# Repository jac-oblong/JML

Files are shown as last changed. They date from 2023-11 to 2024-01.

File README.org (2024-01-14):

* JML
Line of computers built mostly from scrap.

#+CAPTION: JML Logo
#+ATTR_HTML: :width 600px :style margin-left: auto; margin-right: auto;
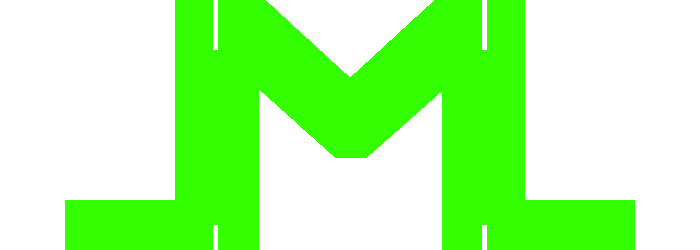
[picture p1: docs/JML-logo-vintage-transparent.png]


* Table of Contents :toc:
- [[#jml][JML]]
- [[#design][Design]]
- [[#parts][Parts]]
- [[#folder-organization][Folder Organization]]
- [[#families][Families]]
  - [[#jml-8][JML-8]]

* Design
The line of *JML* computers is broken into "families". Each family is
designated by a number, for example the *JML-8* family of computer. Each model
in that family is further distinguished by a name, for example the
*JML-8-Mini*.

* Parts
Almost all parts have been scrapped from other computers/electronics. Many of
these parts are from very old computers and are no longer on the market.

Modern day equivalents do exist, but it is necessary to be cautious about
differing pin-outs. It may be necessary to design a new PCB for a modern
chip, or at least a way to change pin-out.

* Folder Organization
Information about the different model computers can be found in any
directory titled *JML-{family}-{model}*.

* Families
Below is a list of all families with a brief description of each family.

- [[#jml-8][JML-8]]

** JML-8
This is a family of 8-bit microcomputers designed around the Z80
microprocessor.

- [[#jml-8-mini][JML-8-Mini]]

*** JML-8-Mini
[[file:jml-8-mini][This model]] uses a UART serial port to communicate with a terminal.
An FTDI chip can be used to send data from a computer to the
Z80.

The "operating system" this model runs only allows for very simple
commands. These commands allow the user to read the values at
memory locations, write values to memory locations and transfer
program control to a specific memory location. Additionally, there is a built
in BASIC interpreter.

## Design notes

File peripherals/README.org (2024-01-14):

* Peripherals
This directory contains information regarding custom peripherals.
Some of the peripherals are designed as add-ons/expansions to other
models, and others are designed as entirely distinct boards that are
in some way related to the *JML* project.

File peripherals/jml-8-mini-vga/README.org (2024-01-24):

* JML-8-Mini VGA

#+ATTR_HTML: :width 600px
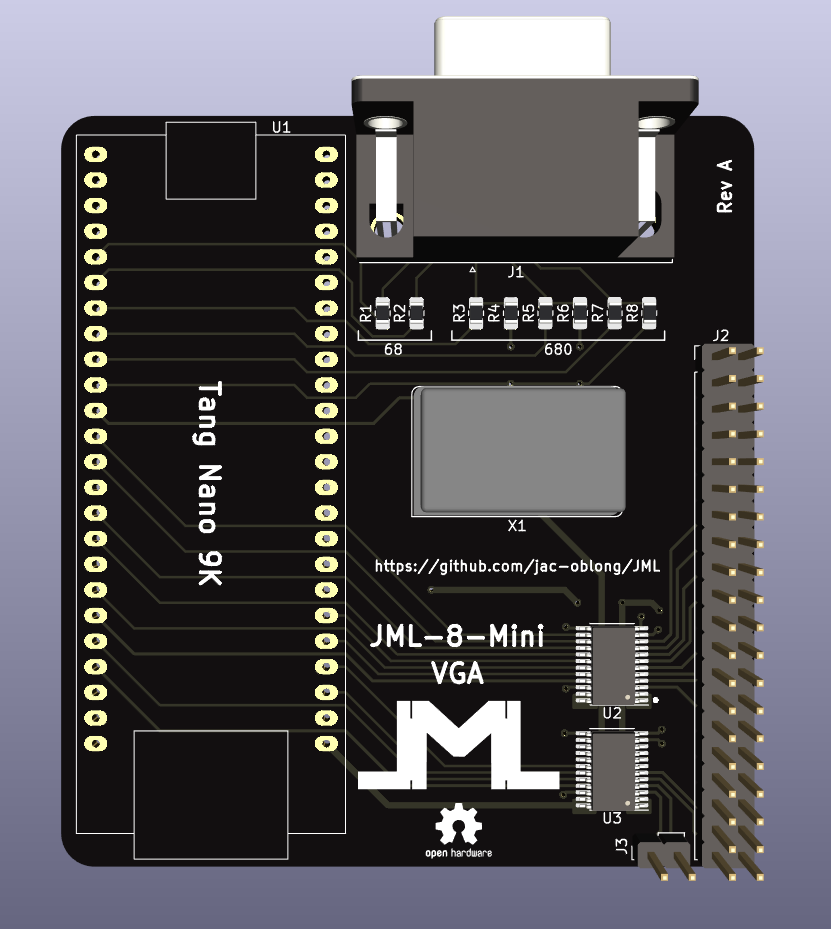
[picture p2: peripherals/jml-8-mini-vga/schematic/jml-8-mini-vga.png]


This provides a VGA interface to the JML-8-Mini via a Tang Nano 9k FPGA.
The daughterboard plugs into the the Z80 header pins on the JML-8-Mini.

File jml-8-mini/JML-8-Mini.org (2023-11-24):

#+title: JML-8-Mini

#+CAPTION: JML-8-Mini PCB
#+ATTR_HTML: :width 600px
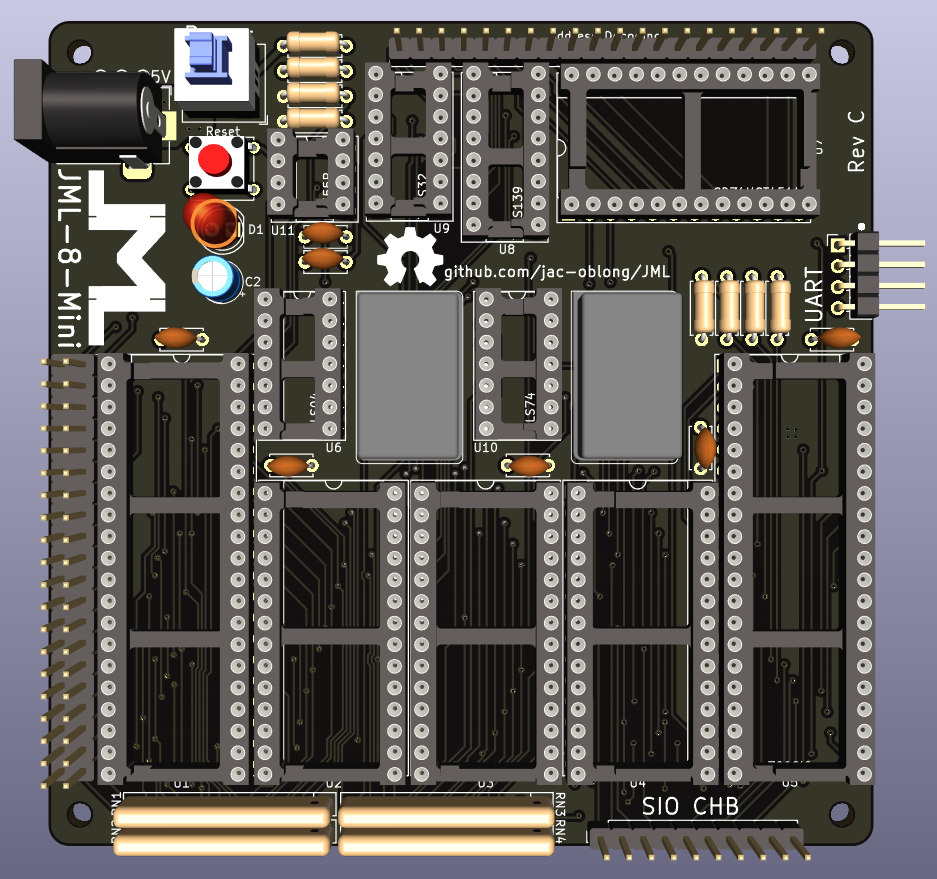
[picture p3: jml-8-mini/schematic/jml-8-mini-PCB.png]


* Table of Contents :toc:
- [[#description--features][Description & Features]]
- [[#usage][Usage]]
  - [[#creating-your-own][Creating Your Own]]
- [[#design-overview][Design Overview]]

* Description & Features
The *JML-8-Mini* is an 8-bit computer using the Z80 microprocessor. The computer
has a built-in BASIC interpreter as well as a simple memory monitor.

*Features:*
 - 8k of ROM (BASIC and Memory Monitor)
 - 32k of RAM
 - BASIC Interpreter (Based on Grant Searle's Version of NASCOM BASIC)
 - UART Interface (Z80 SIO & Z80 CTC)
 - Extra Serial I/0 Port (Z80 SIO CHB)
 - 3 Extra Counter/Timer Circuits (Z80 CTC CH1-3)

* Usage
The barrel jack can be used to power the board. It requires 5V DC
center-positive.

Since the computer communicates over UART, a device that accepts serial
communication is needed. If using a computer, an FTDI device or even a
micro-controller can be used to convert from UART to USB. Any terminal
application should work for communication. The UART protocol used is 8-N-1
at 9600 baud. The order of the UART connection (starting on the end of the
connector with the black dot) is GND-TX-RX-CTS, NOTE: those labels are from
the viewpoint of an external device, not the JML-8-Mini.

On boot-up, the computer will be placed in the memory monitor program. BASIC
can be entered by pressing 'B' (case does not matter). However, there are
four other commands:
 - *W*: Write data into memory. After pressing 'W', enter the location in
   memory to write to in hex (4 digits required). Then, write the data to be
   written starting at that location. All data must be formatted in hex (2
   digits) and separated by another character (the character does not matter).
   A newline (carriage return)(0x0D) will signify that the write has ended.
 - *R*: Read data from memory. After pressing 'R', enter the location in
   memory to read from in hex (4 digits required). Then enter a dummy
   character, followed by the location in memory to stop reading from in hex.
   A newline will begin printing the data (in hex).
 - *J*: Jump to a location in memory. After pressing 'J', enter the location
   in memory to jump to in hex (4 digits required). The computer will execute
   an unconditional jump to that location.
 - *C*: Clear the screen.

** Creating Your Own
The [[file:./schematic/jml-8-mini-schematic.pdf][schematic]], [[file:./schematic/gerber][gerbers]] and [[file:./case/][case]] are all available in this repository. Be
careful when sourcing components; the CD74HCT4514E is a 4-16 line decoder,
but does not have the same footprint as other 4-16 decoders. A way to change
pin-outs may be necessary.

The BASIC code can be obtained from [[http://searle.wales][Grant Searle's Website]]. There are only
two changes that need to be made:
  1) Around line 130, there is a line with ~.org 04000H~, this needs to be
     changed to ~.org 00380H~
  2) At the very end of the file, the ~.end~ should be removed
Everything else can stay the same. The file should be named "basic.s" and
placed in the [[file:./src/][src]] directory.

There is [[file:../related-projects/][Arduino-based EEPROM programmer]] that may be helpful.

* Design Overview
The *JML-8-Mini*'s memory map can be seen below.

#+CAPTION: JML-8-Mini Memory Map
#+ATTR_HTML: :width 400px
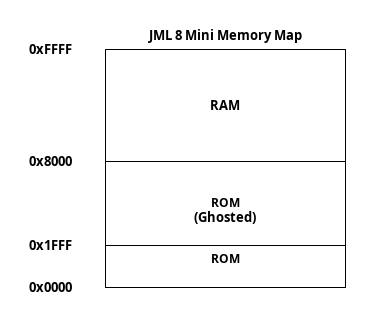
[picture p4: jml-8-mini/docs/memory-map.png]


The section of memory between ~0x1FFF~ and ~0x8000~ is a repetition of the ROM
because the ROM will still be enabled.

The I/O memory map is shown below.

#+CAPTION: JML-8-Mini Memory Map
#+ATTR_HTML: :width 300px
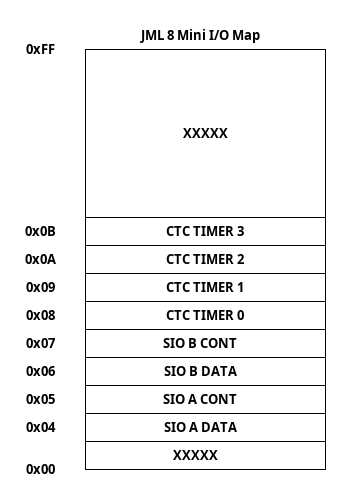
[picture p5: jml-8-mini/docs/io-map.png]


The extra headers on the board (address decoding, Z80 lines, SIO-CHB) allow
for more features to be added as I/O.

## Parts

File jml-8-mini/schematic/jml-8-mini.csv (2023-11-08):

# | Reference | Qty | Value | Footprint | DNP
1 | C1 | 1 | 0.001uF | Capacitor_THT:C_Disc_D5.0mm_W2.5mm_P5.00mm
2 | C2 | 1 | 1uF | Capacitor_THT:CP_Radial_D5.0mm_P2.50mm
3 | C3 | 1 | 0.1uF | Capacitor_THT:C_Disc_D5.0mm_W2.5mm_P5.00mm
4 | C4, C5, C6, C7, C8 | 5 | 2.2uF | Capacitor_THT:C_Disc_D5.0mm_W2.5mm_P5.00mm
5 | D1 | 1 | RED | LED_THT:LED_D5.0mm
6 | H1, H2, H3, H4 | 4 | MountingHole | MountingHole:MountingHole_2.7mm_M2.5
7 | J1 | 1 | BarrelJack | Connector_BarrelJack:BarrelJack_Horizontal
8 | J2 | 1 | SIO CHB | Connector_PinHeader_2.54mm:PinHeader_1x10_P2.54mm_Vertical
9 | J3 | 1 | UART | Connector_PinHeader_2.54mm:PinHeader_1x04_P2.54mm_Horizontal
10 | J5 | 1 | Address Decoding | Connector_PinHeader_2.54mm:PinHeader_1x20_P2.54mm_Vertical
11 | J6 | 1 | Z80 Lines | Connector_PinHeader_2.54mm:PinHeader_2x20_P2.54mm_Vertical
12 | R1, R2, R3, R8 | 4 | 4K7 | Resistor_THT:R_Axial_DIN0207_L6.3mm_D2.5mm_P7.62mm_Horizontal
13 | R4 | 1 | 100K | Resistor_THT:R_Axial_DIN0207_L6.3mm_D2.5mm_P7.62mm_Horizontal
14 | R5 | 1 | 47K | Resistor_THT:R_Axial_DIN0207_L6.3mm_D2.5mm_P7.62mm_Horizontal
15 | R6 | 1 | 10K | Resistor_THT:R_Axial_DIN0207_L6.3mm_D2.5mm_P7.62mm_Horizontal
16 | R7 | 1 | 2K2 | Resistor_THT:R_Axial_DIN0207_L6.3mm_D2.5mm_P7.62mm_Horizontal
17 | RN1, RN2, RN3, RN4 | 4 | 10K | Resistor_THT:R_Array_SIP10
18 | SW1 | 1 | Reset | Button_Switch_THT:SW_Tactile_Straight_KSA0Axx1LFTR
19 | SW2 | 1 | Power | Button_Switch_THT:SW_Push_2P2T_Toggle_CK_PVA2xxH1xxxxxxV2
20 | U1 | 1 | Z80CPU | Package_DIP:DIP-40_W15.24mm_Socket_LongPads
21 | U2 | 1 | 28HC64 | Package_DIP:DIP-28_W15.24mm_Socket_LongPads
22 | U3 | 1 | 60L256 | Package_DIP:DIP-28_W15.24mm_Socket_LongPads
23 | U4 | 1 | Z80CTC | Package_DIP:DIP-28_W15.24mm_Socket_LongPads
24 | U5 | 1 | Z80SIO | Package_DIP:DIP-40_W15.24mm_Socket_LongPads
25 | U6 | 1 | 74LS04 | Package_DIP:DIP-14_W7.62mm_Socket_LongPads
26 | U7 | 1 | CD74HCT4514E | Package_DIP:DIP-24_W15.24mm_Socket_LongPads
27 | U8 | 1 | 74LS139 | Package_DIP:DIP-16_W7.62mm_Socket_LongPads
28 | U9 | 1 | 74LS32 | Package_DIP:DIP-14_W7.62mm_Socket_LongPads
29 | U10 | 1 | 74LS74 | Package_DIP:DIP-14_W7.62mm_Socket_LongPads
30 | U11 | 1 | NE555P | Package_DIP:DIP-8_W7.62mm_Socket_LongPads
31 | X1 | 1 | 8MHz | Oscillator:Oscillator_DIP-14
32 | X2 | 1 | 2.4576MHz | Oscillator:Oscillator_DIP-14

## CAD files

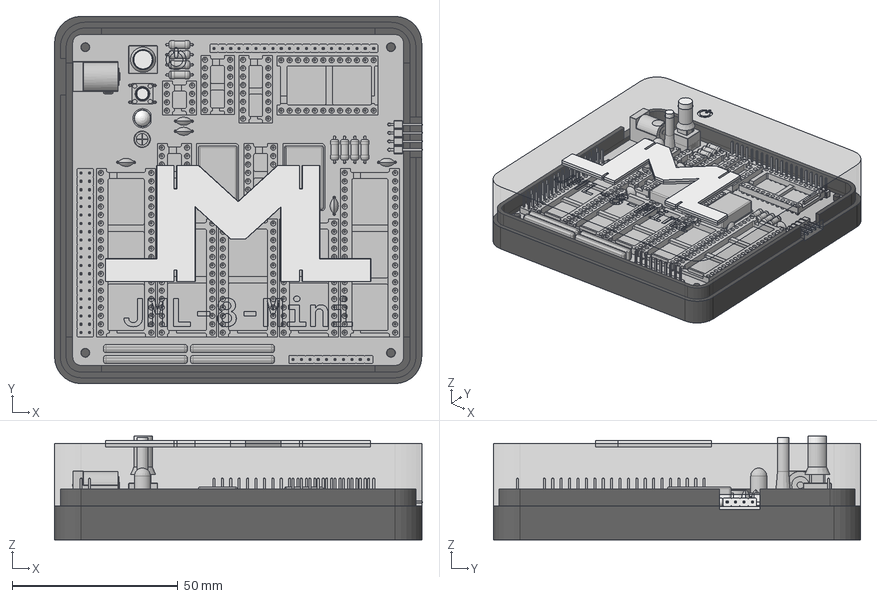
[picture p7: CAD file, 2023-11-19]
jml-8-mini/case/jml-8-mini-case-assembly.FCStd
111.2 x 110.9 x 31.3 mm
jml-8-mini-case-bottom_bottom_001
jml-8-mini1_001
jml-8-mini-case-top_reset-peg_001
jml-8-mini-case-top_power-peg_001
jml-8-mini-case-top_logo-fill_001
jml-8-mini-case-top_top-cut_001

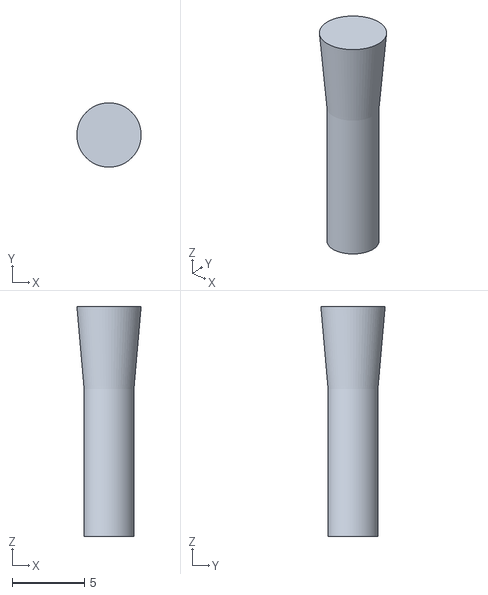
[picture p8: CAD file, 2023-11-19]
jml-8-mini/case/jml-8-mini-case-reset-peg.stl
4.45 x 4.45 x 15.9

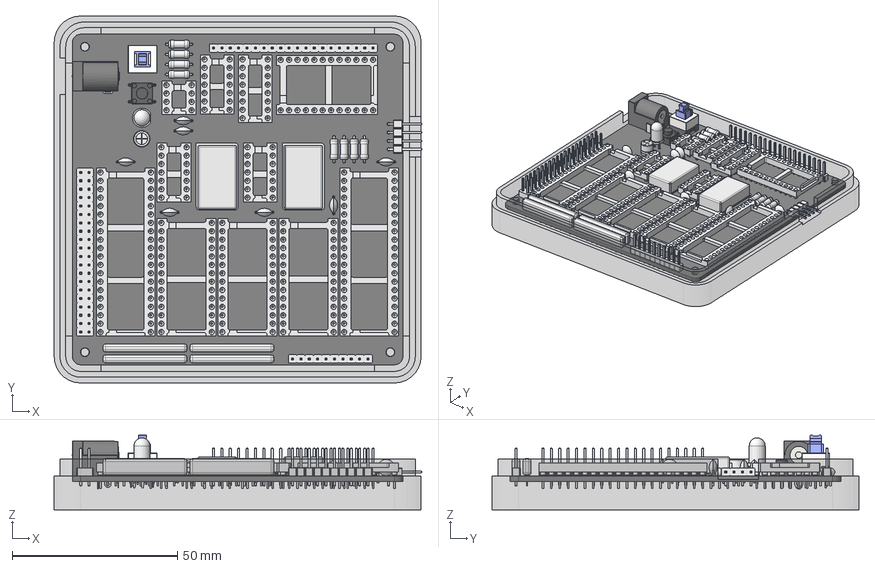
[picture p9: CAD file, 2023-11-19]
jml-8-mini/case/jml-8-mini-case-bottom.FCStd
111.2 x 110.9 x 22.6 mm
Pcb_da37
R1_R_Axial_DIN0207_L63mm_D25mm_P762mm_Horizontal_fb2dbf7774b0
U1_DIP_40_W1524mm_Socket_2b005913294a
X2_Oscillator_DIP-14_1cb9fdc6376d
U8_DIP_16_W762mm_Socket_50c2e2878be6
D1_LED_D5.0mm_c46ec44da1f9
U11_DIP_8_W762mm_Socket_8dfed9607c42
U3_DIP_28_W1524mm_Socket_90a58a7486b6
RN3_R_Array_SIP10_876d0d87e7f4
C5_C_Disc_D50mm_W25mm_P500mm_e6d4c14bf3d8
R1_R_Axial_DIN0207_L63mm_D25mm_P762mm_Horizontal_fb2dbf7774b001
C2_CP_Radial_D50mm_P250mm_b76e36c16755
RN3_R_Array_SIP10_876d0d87e7f005
U7_DIP_24_W1524mm_Socket_14ec14ce778c
U1_DIP_40_W1524mm_Socket_2b005913294a001
RN3_R_Array_SIP10_876d0d87e7f006
C5_C_Disc_D50mm_W25mm_P500mm_e6d4c14bf3d009
U9_DIP_14_W762mm_Socket_89bedef5e4b6
J2_PinHeader_1x10_P254mm_Vertical_b87f2ee21f90
SW1_buttonRot_e16b7170c22b
R1_R_Axial_DIN0207_L63mm_D25mm_P762mm_Horizontal_fb2dbf7774b002
U3_DIP_28_W1524mm_Socket_90a58a7486b007
J6_PinHeader_2x20_P254mm_Vertical_cfeccff21bfa
BarrelJack_Horizontal
BarrelJack_Horizontal001
BarrelJack_Horizontal002
BarrelJack_Horizontal003
BarrelJack_Horizontal004
ON_ON_7x7mm_6pin v014
ON_ON_7x7mm_6pin v015
ON_ON_7x7mm_6pin v016
ON_ON_7x7mm_6pin v017
ON_ON_7x7mm_6pin v018
ON_ON_7x7mm_6pin v019
ON_ON_7x7mm_6pin v020
ON_ON_7x7mm_6pin v021
ON_ON_7x7mm_6pin v022
R1_R_Axial_DIN0207_L63mm_D25mm_P762mm_Horizontal_fb2dbf7774b003
C5_C_Disc_D50mm_W25mm_P500mm_e6d4c14bf3d010
R1_R_Axial_DIN0207_L63mm_D25mm_P762mm_Horizontal_fb2dbf7774b004
J5_PinHeader_1x20_P254mm_Vertical_dfc64bbc94d7
R1_R_Axial_DIN0207_L63mm_D25mm_P762mm_Horizontal_fb2dbf7774b005
R1_R_Axial_DIN0207_L63mm_D25mm_P762mm_Horizontal_fb2dbf7774b006
C5_C_Disc_D50mm_W25mm_P500mm_e6d4c14bf3d011
RN3_R_Array_SIP10_876d0d87e7f007
C5_C_Disc_D50mm_W25mm_P500mm_e6d4c14bf3d012
C5_C_Disc_D50mm_W25mm_P500mm_e6d4c14bf3d013
U3_DIP_28_W1524mm_Socket_90a58a7486b008
R1_R_Axial_DIN0207_L63mm_D25mm_P762mm_Horizontal_fb2dbf7774b007
J3_PinHeader_1x04_P254mm_Horizontal_bb1bdafc893f
C5_C_Disc_D50mm_W25mm_P500mm_e6d4c14bf3d014
U9_DIP_14_W762mm_Socket_89bedef5e4b007
X2_Oscillator_DIP-14_1cb9fdc6376d001
U9_DIP_14_W762mm_Socket_89bedef5e4b008
bottom

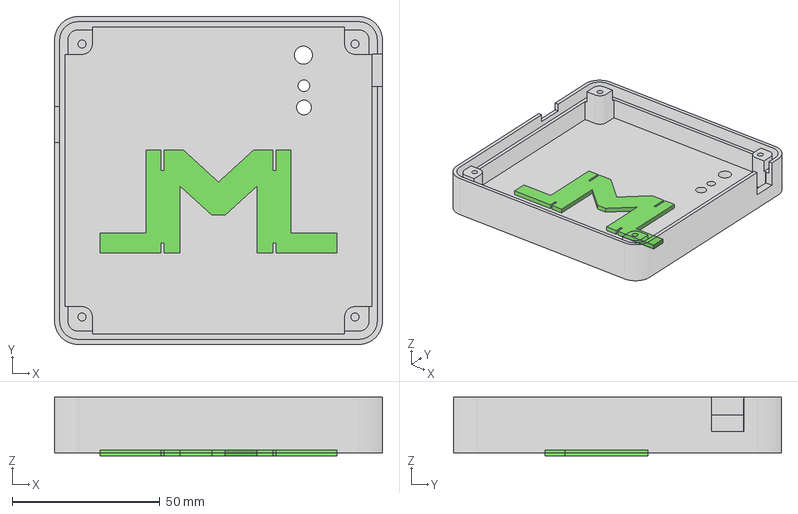
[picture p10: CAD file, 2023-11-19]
jml-8-mini/case/jml-8-mini-case-top.FCStd
110.9 x 110.9 x 19.9 mm
top-cut
logo-fill

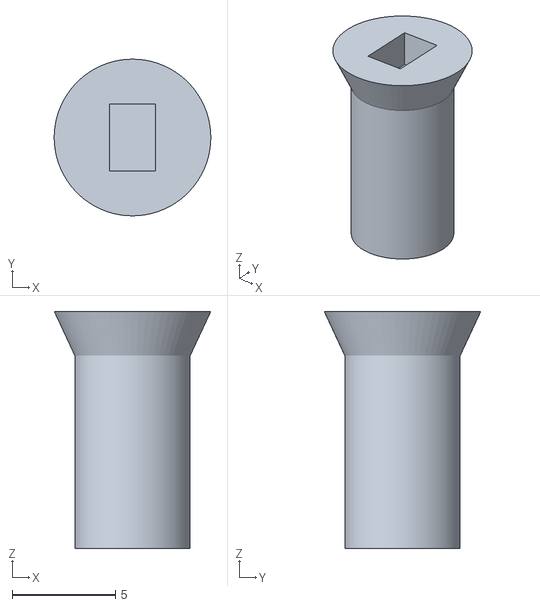
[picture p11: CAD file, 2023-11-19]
jml-8-mini/case/jml-8-mini-case-power-peg.stl
7.60 x 7.60 x 11.5

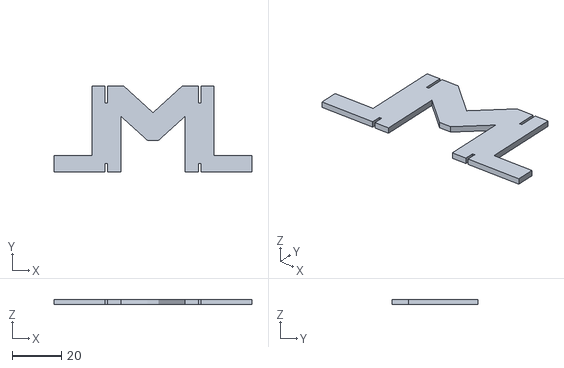
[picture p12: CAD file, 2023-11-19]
jml-8-mini/case/jml-8-mini-case-logo.stl
80.0 x 35.0 x 2.00

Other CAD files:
jml-8-mini/case/jml-8-mini-case-bottom.stl
jml-8-mini/case/jml-8-mini-case-top.stl

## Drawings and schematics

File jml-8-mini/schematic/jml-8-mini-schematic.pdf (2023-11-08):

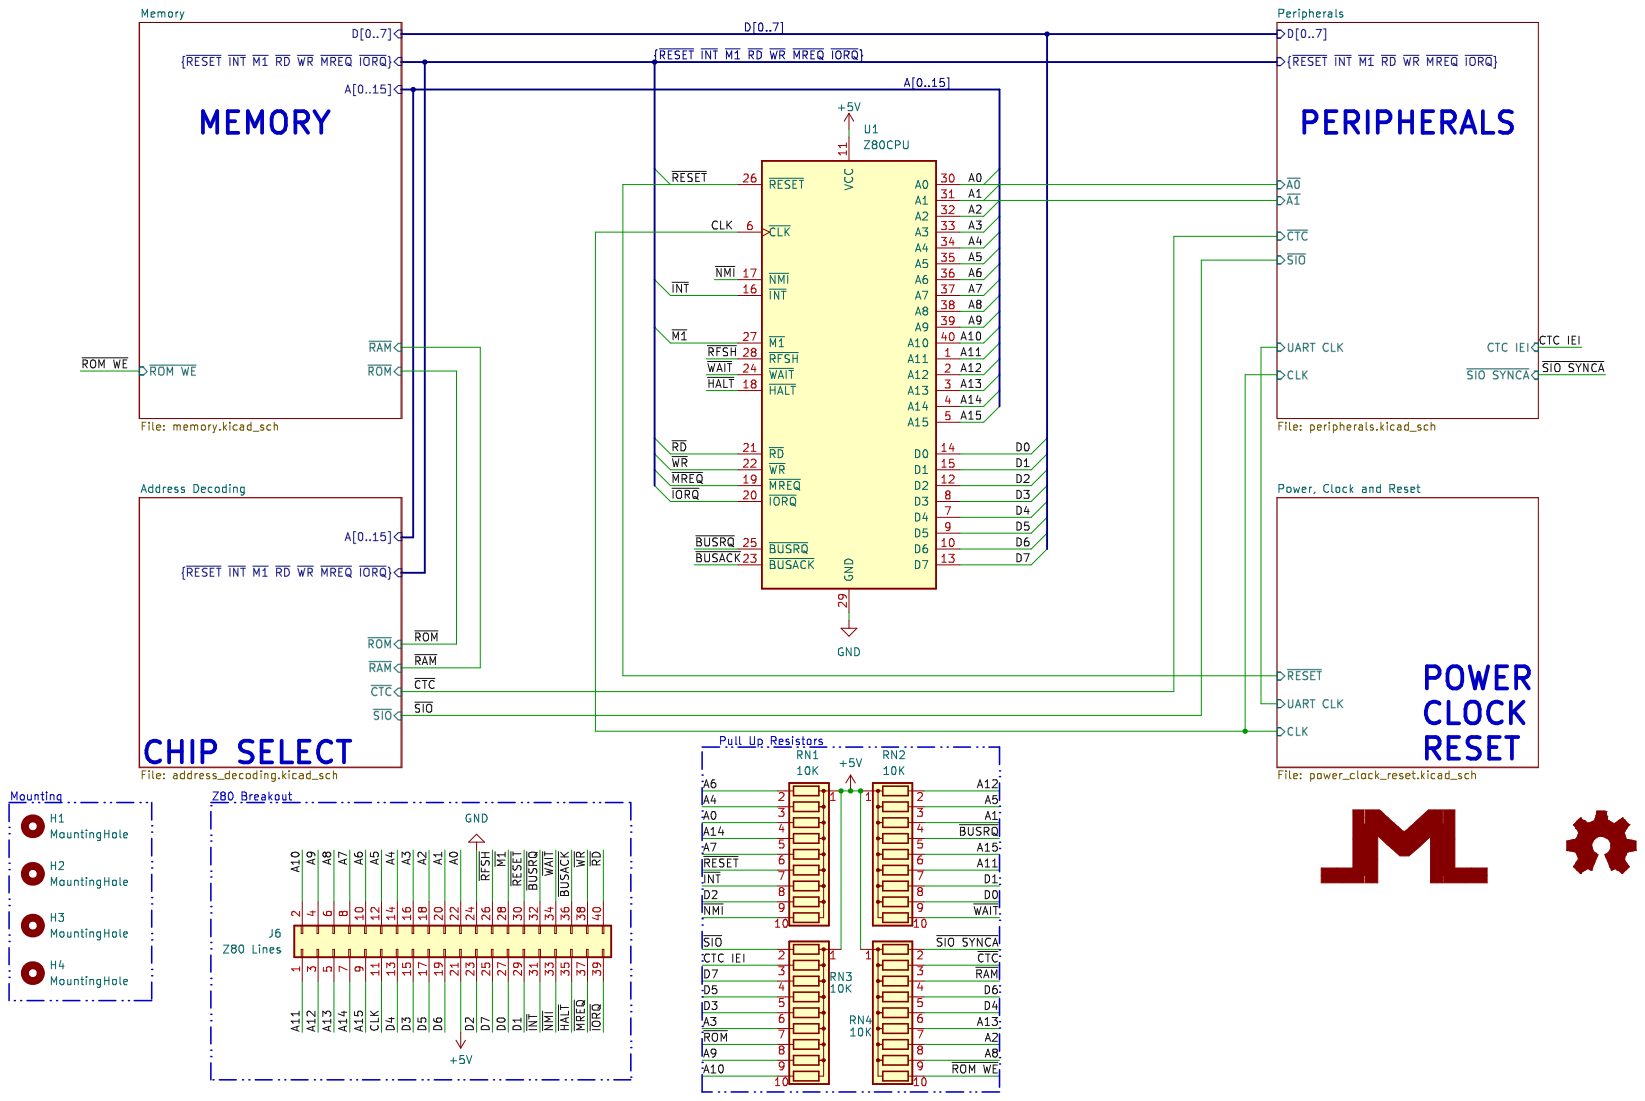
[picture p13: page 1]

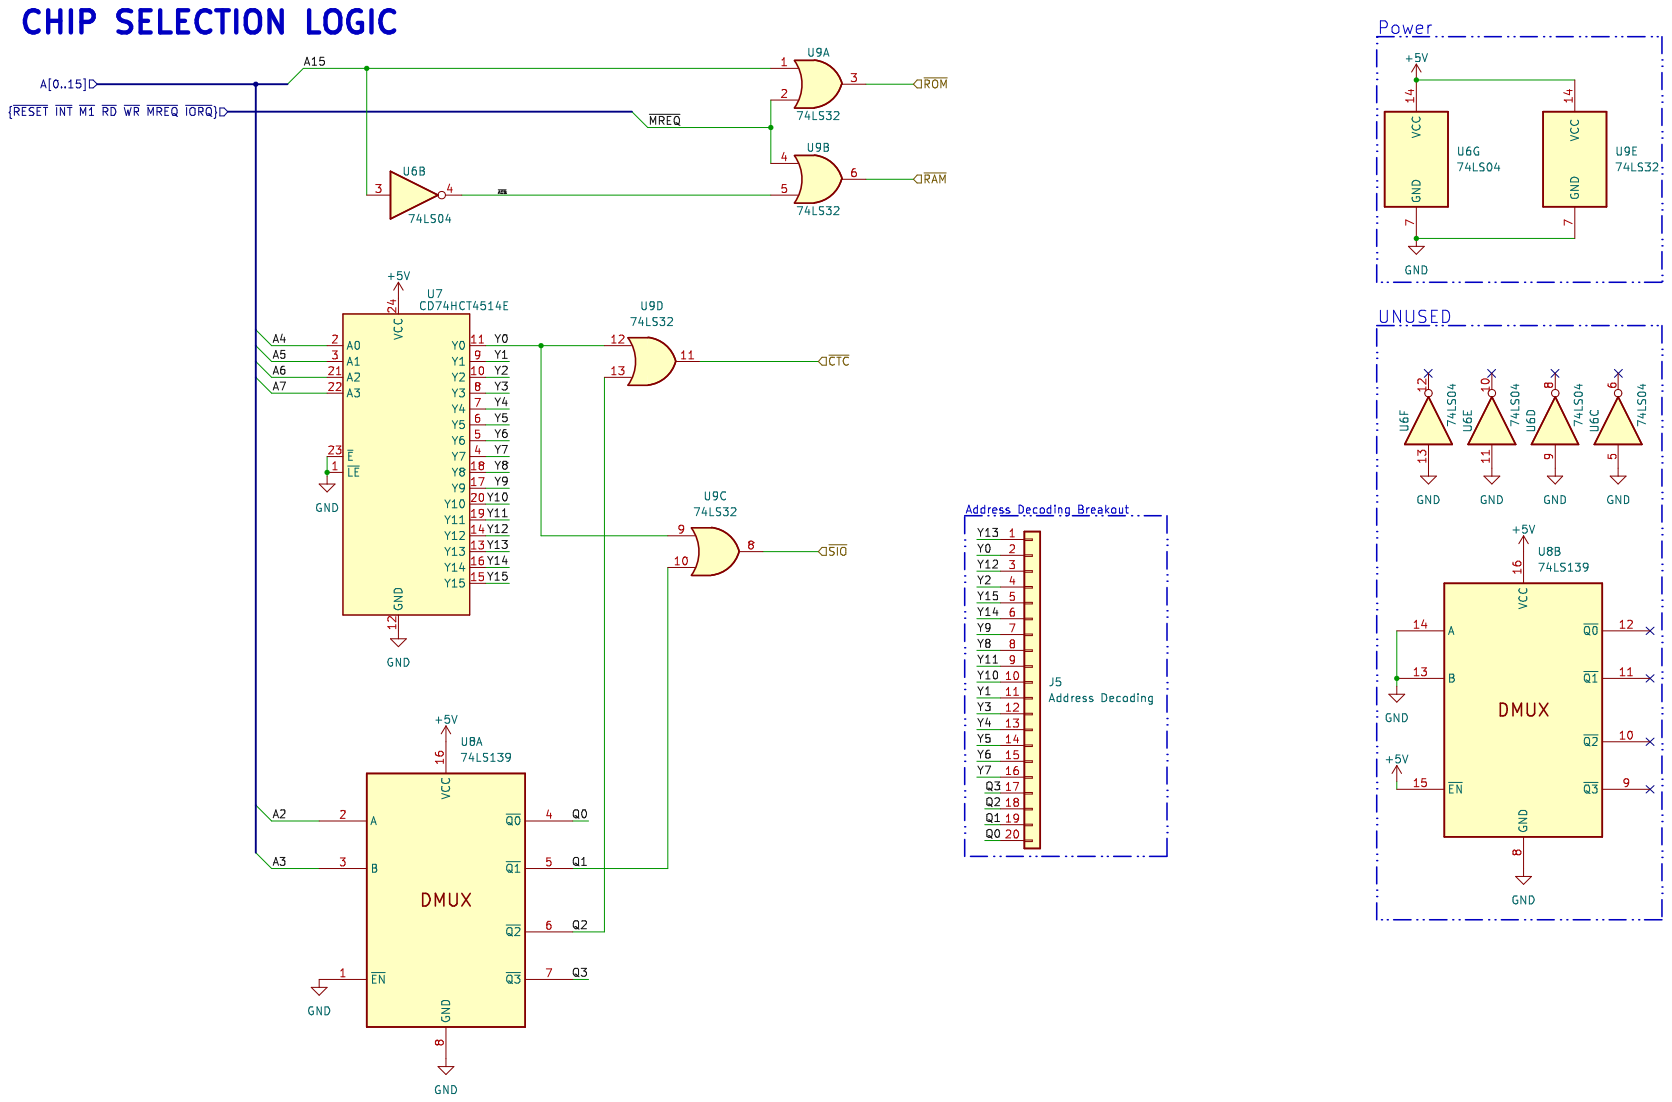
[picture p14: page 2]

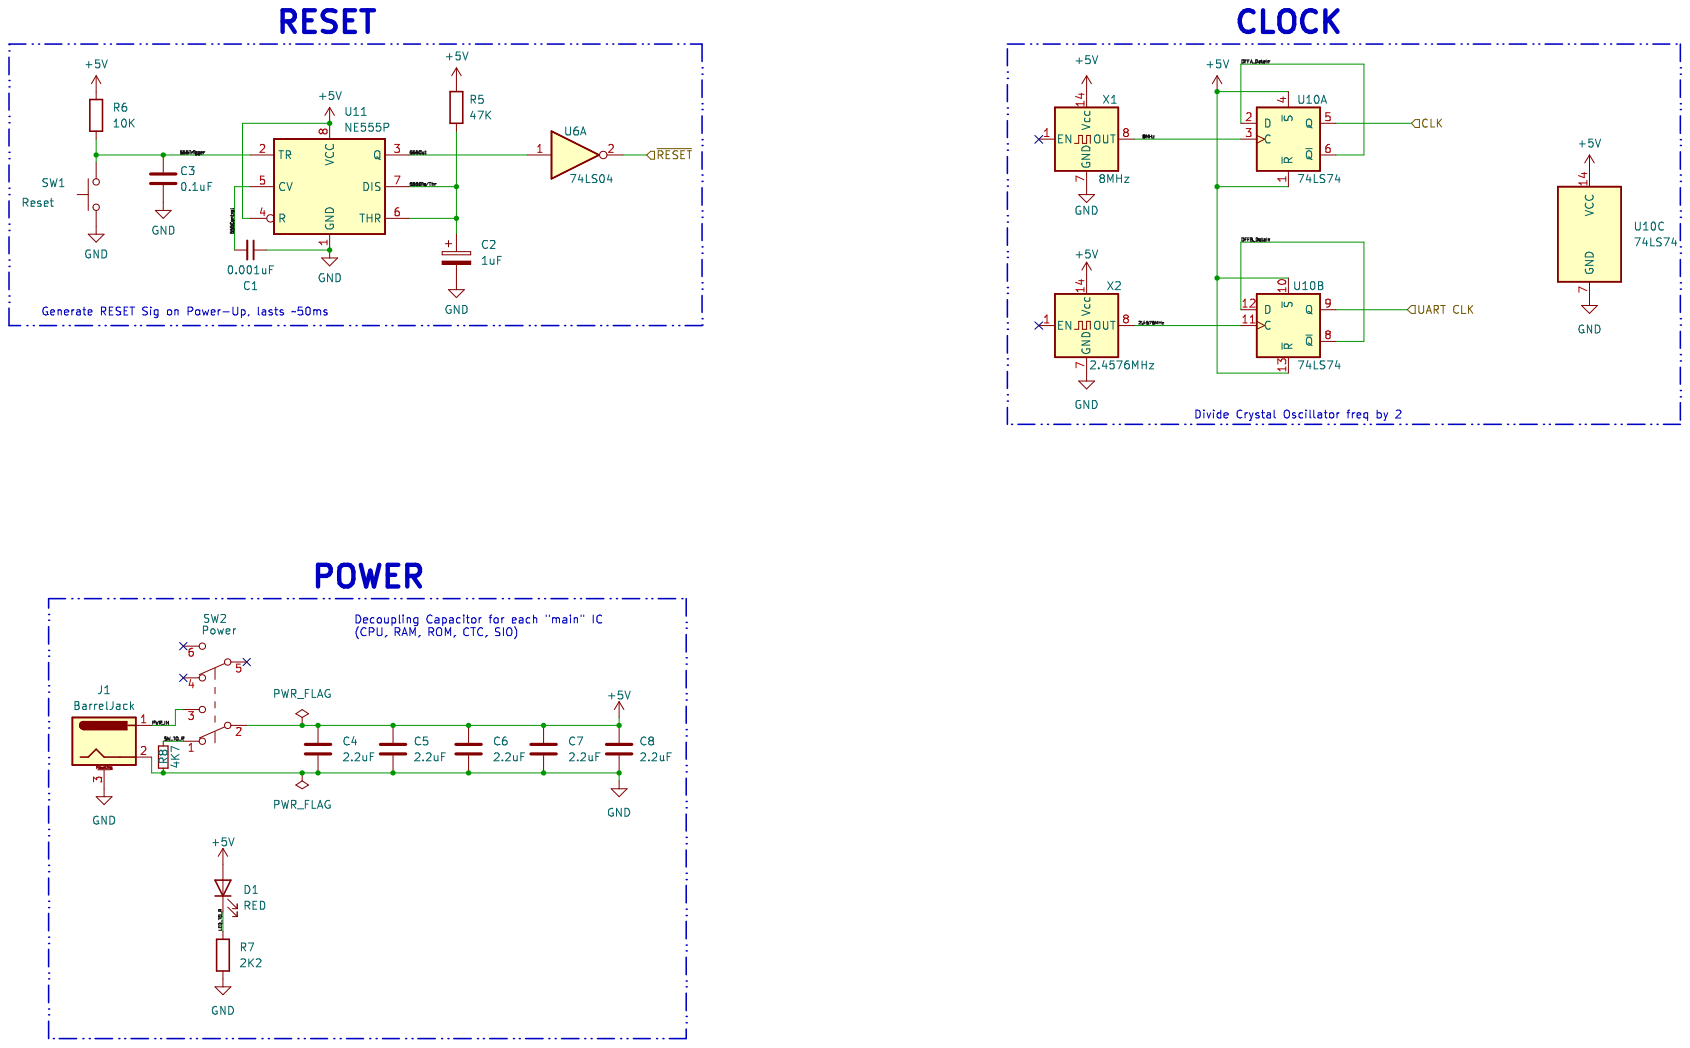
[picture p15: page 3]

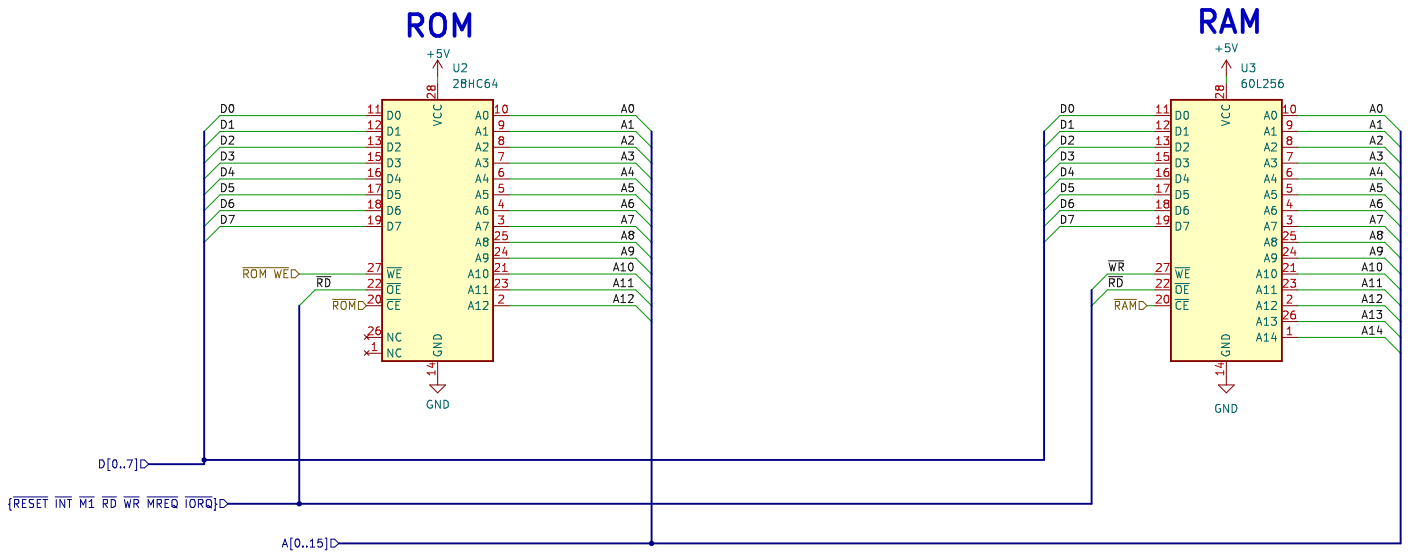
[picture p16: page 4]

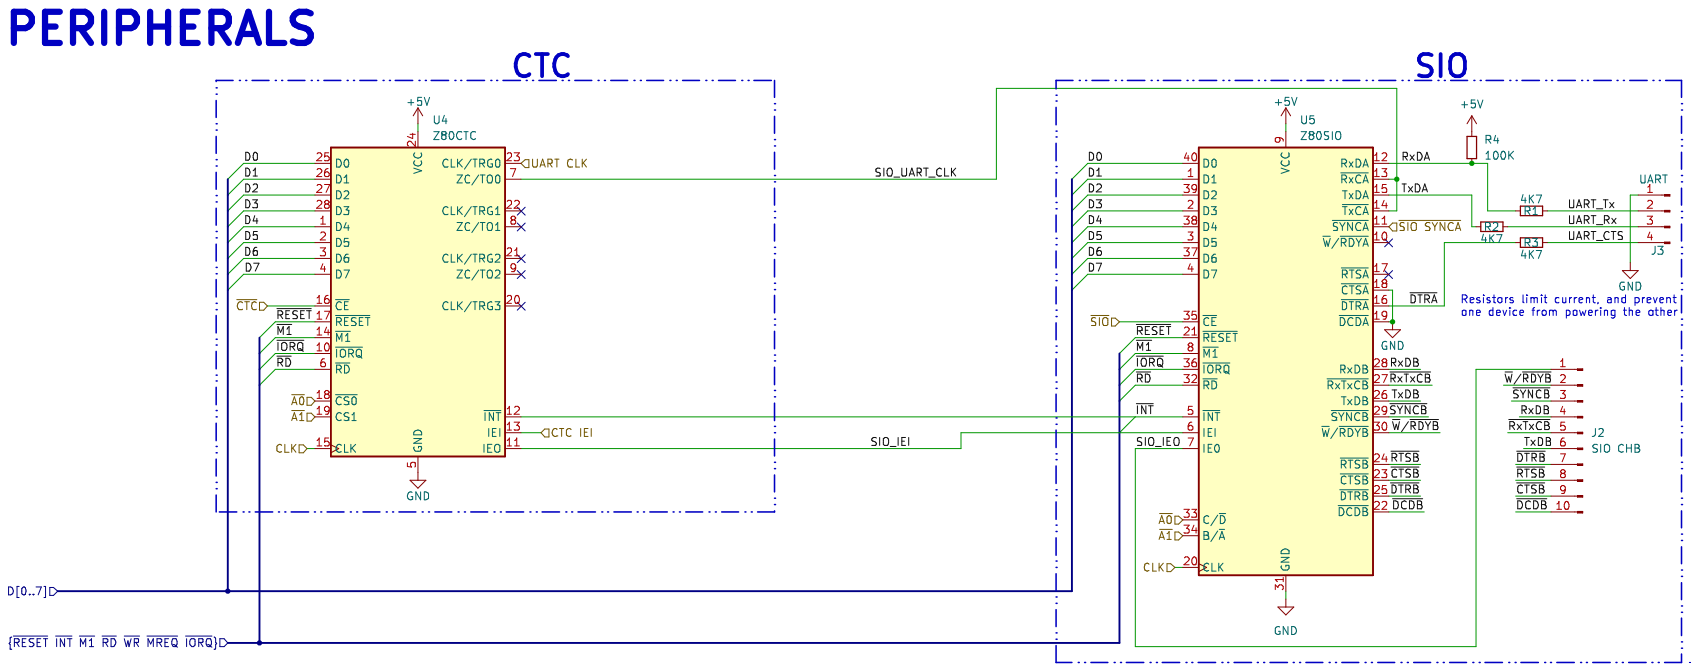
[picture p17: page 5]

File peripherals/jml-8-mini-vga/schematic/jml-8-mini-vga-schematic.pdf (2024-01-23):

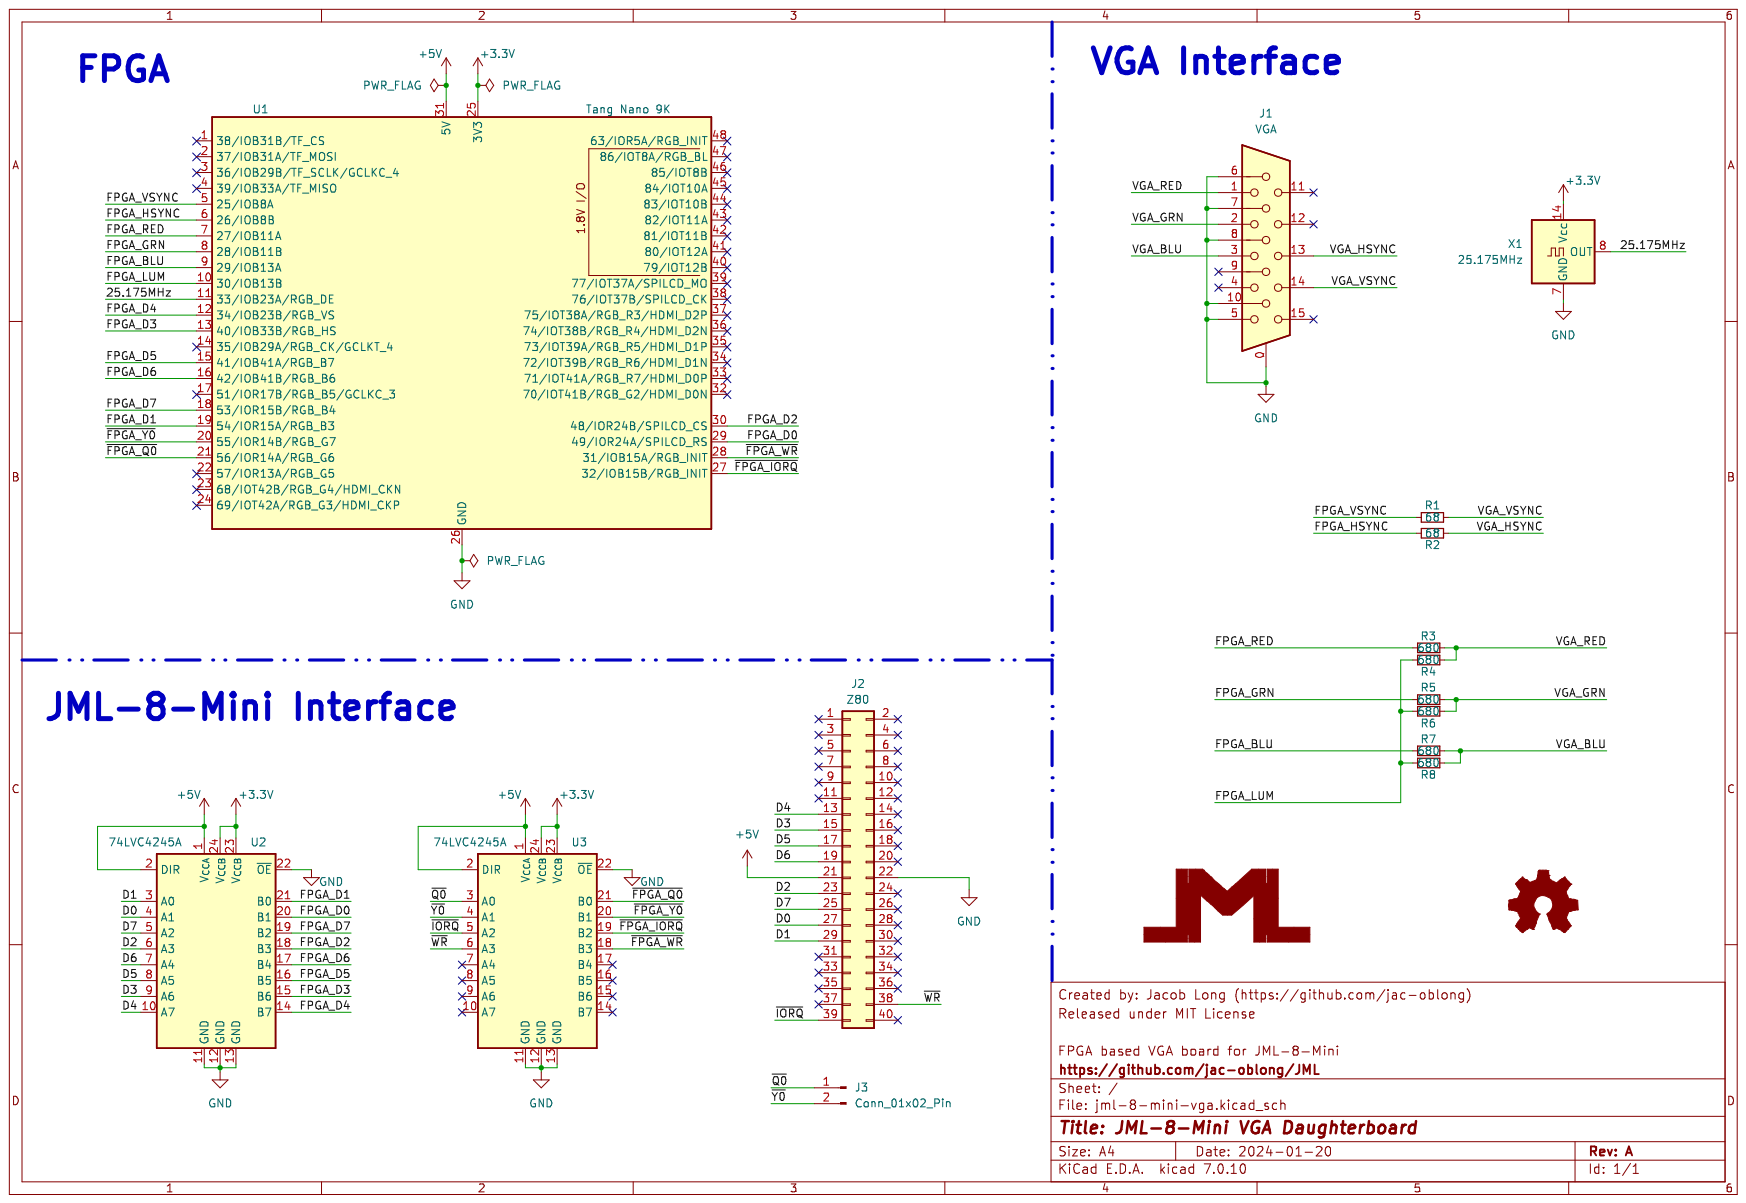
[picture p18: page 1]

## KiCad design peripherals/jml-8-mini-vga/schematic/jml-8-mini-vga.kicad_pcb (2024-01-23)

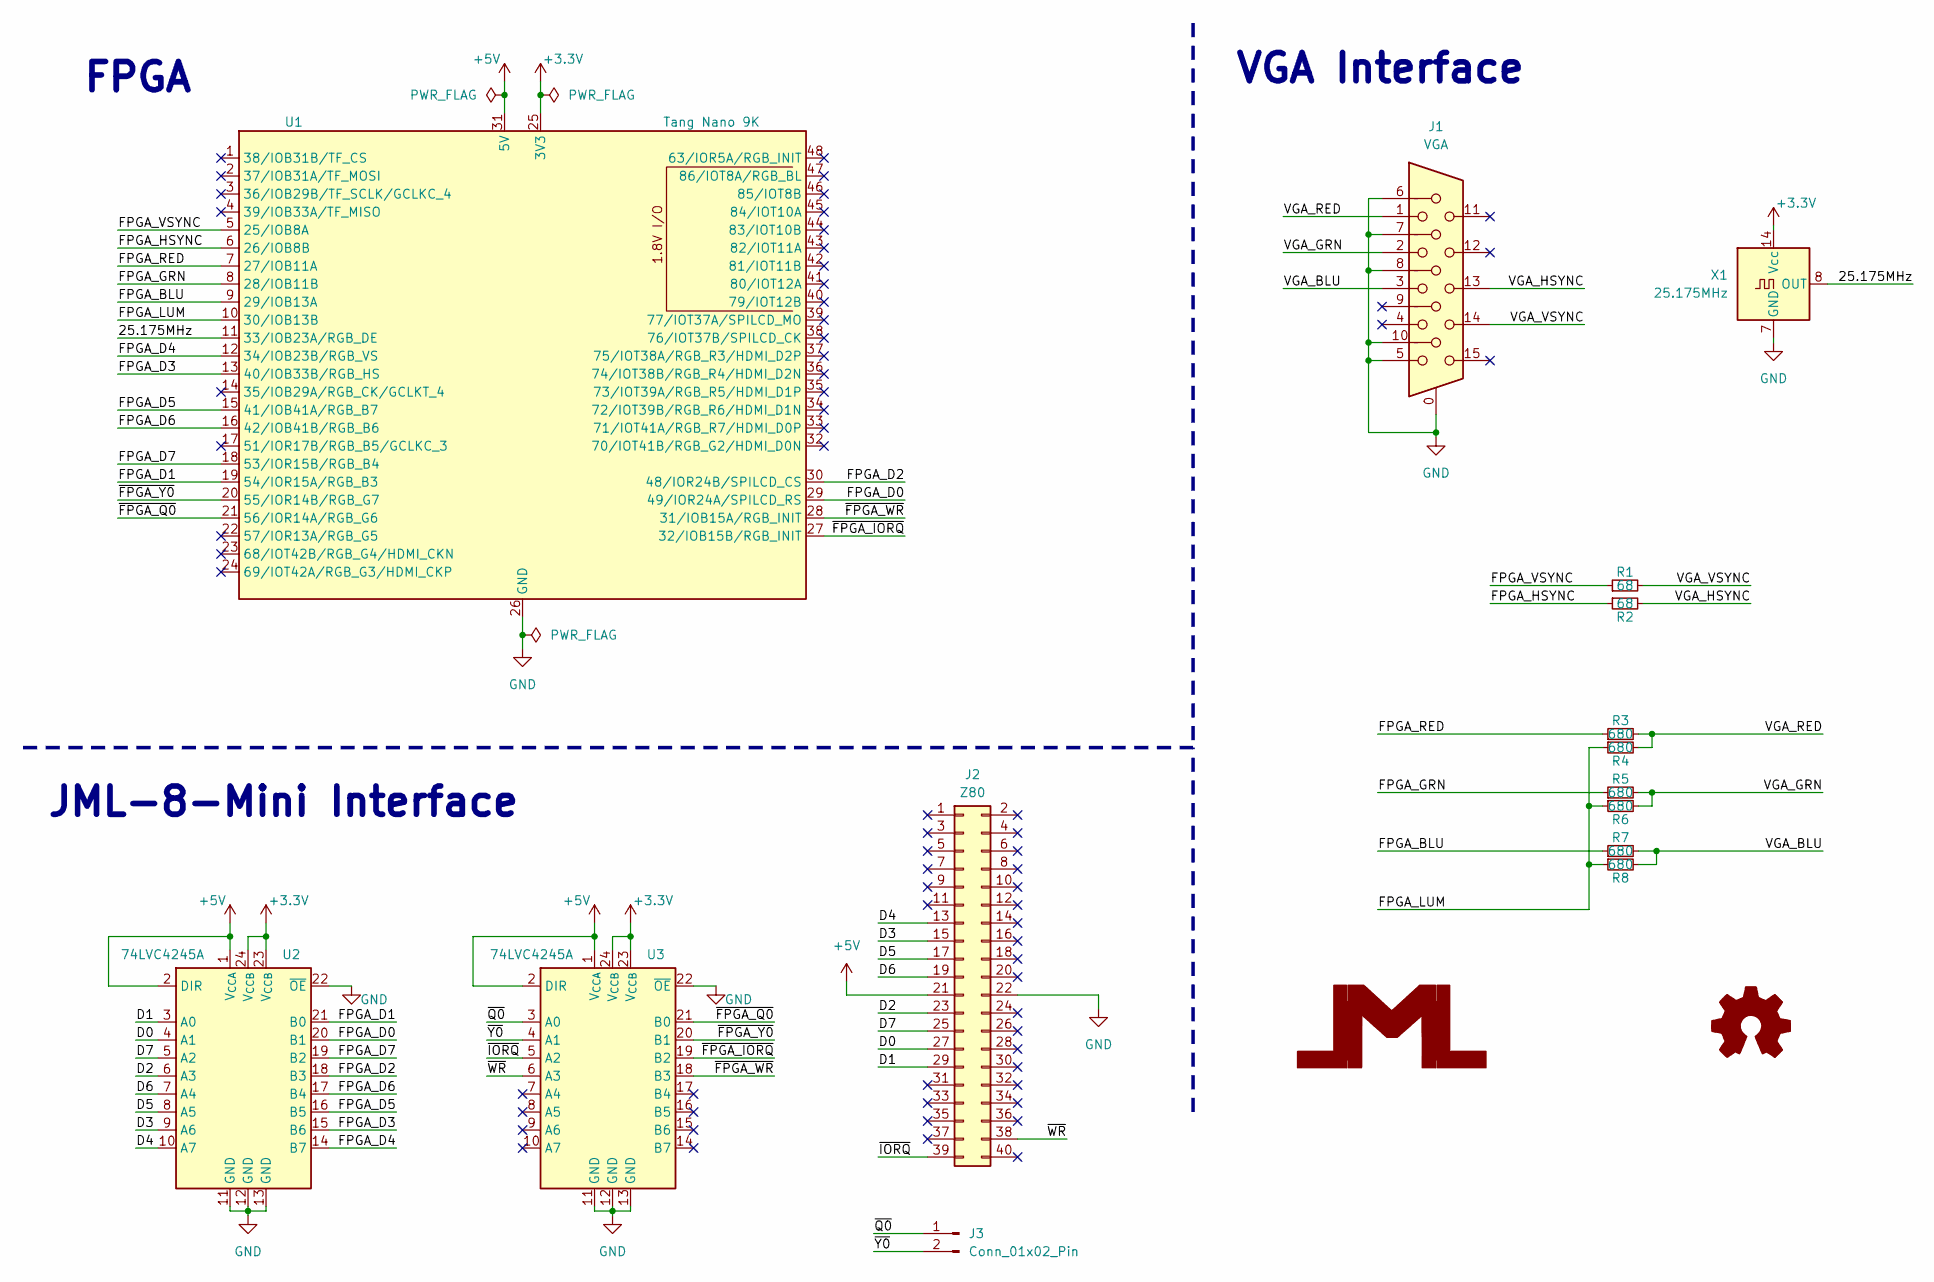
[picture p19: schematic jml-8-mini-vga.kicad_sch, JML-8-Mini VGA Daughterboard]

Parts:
J1: VGA; DSUB-15-HD_Female_Horizontal_P2.29x1.98mm_EdgePinOffset8.35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
J2: Z80; PinHeader_2x20_P2.54mm_Vertical
J3: Conn_01x02_Pin; PinHeader_1x02_P2.54mm_Vertical
R1, R2: 68; R_0805_2012Metric_Pad1.20x1.40mm_HandSolder
R3, R4, R5, R6, R7, R8: 680; R_0805_2012Metric_Pad1.20x1.40mm_HandSolder
U1: Tang Nano 9K; TangNano9k
U2, U3: 74LVC4245A; TSSOP-24_4.4x7.8mm_P0.65mm
X1: 25.175MHz; Oscillator_DIP-14

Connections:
+3.3V: U1.25 (3V3), U2.23 (V_{CCB}), U2.24 (V_{CCB}), U3.23 (V_{CCB}), U3.24 (V_{CCB}), X1.14 (Vcc)
+5V: J2.21, U1.31 (5V), U2.1 (V_{CCA}), U2.2 (DIR), U3.1 (V_{CCA}), U3.2 (DIR)
/25.175MHz: U1.11 (33/IOB23A/RGB_DE), X1.8 (OUT)
/D0: J2.27, U2.4 (A1)
/D1: J2.29, U2.3 (A0)
/D2: J2.23, U2.6 (A3)
/D3: J2.15, U2.9 (A6)
/D4: J2.13, U2.10 (A7)
/D5: J2.17, U2.8 (A5)
/D6: J2.19, U2.7 (A4)
/D7: J2.25, U2.5 (A2)
/FPGA_BLU: R7.1, U1.9 (29/IOB13A)
/FPGA_D0: U1.29 (49/IOR24A/SPILCD_RS), U2.20 (B1)
/FPGA_D1: U1.19 (54/IOR15A/RGB_B3), U2.21 (B0)
/FPGA_D2: U1.30 (48/IOR24B/SPILCD_CS), U2.18 (B3)
/FPGA_D3: U1.13 (40/IOB33B/RGB_HS), U2.15 (B6)
/FPGA_D4: U1.12 (34/IOB23B/RGB_VS), U2.14 (B7)
/FPGA_D5: U1.15 (41/IOB41A/RGB_B7), U2.16 (B5)
/FPGA_D6: U1.16 (42/IOB41B/RGB_B6), U2.17 (B4)
/FPGA_D7: U1.18 (53/IOR15B/RGB_B4), U2.19 (B2)
/FPGA_GRN: R5.1, U1.8 (28/IOB11B)
/FPGA_HSYNC: R2.1, U1.6 (26/IOB8B)
/FPGA_LUM: R4.1, R6.1, R8.1, U1.10 (30/IOB13B)
/FPGA_RED: R3.1, U1.7 (27/IOB11A)
/FPGA_VSYNC: R1.1, U1.5 (25/IOB8A)
/VGA_BLU: J1.3, R7.2, R8.2
/VGA_GRN: J1.2, R5.2, R6.2
/VGA_HSYNC: J1.13, R2.2
/VGA_RED: J1.1, R3.2, R4.2
/VGA_VSYNC: J1.14, R1.2
/~FPGA_IORQ: U1.27 (32/IOB15B/RGB_INIT), U3.19 (B2)
/~FPGA_Q0: U1.21 (56/IOR14A/RGB_G6), U3.21 (B0)
/~FPGA_WR: U1.28 (31/IOB15A/RGB_INIT), U3.18 (B3)
/~FPGA_Y0: U1.20 (55/IOR14B/RGB_G7), U3.20 (B1)
/~IORQ: J2.39, U3.5 (A2)
/~Q0: J3.1, U3.3 (A0)
/~WR: J2.38, U3.6 (A3)
/~Y0: J3.2, U3.4 (A1)
GND: J1.0, J1.5, J1.6, J1.7, J1.8, J1.10, J2.22, U1.26 (GND), U2.11 (GND), U2.12 (GND), U2.13 (GND), U2.22 (~OE), U3.11 (GND), U3.12 (GND), U3.13 (GND), U3.22 (~OE), X1.7 (GND)

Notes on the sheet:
VGA Interface
JML-8-Mini Interface
FPGA

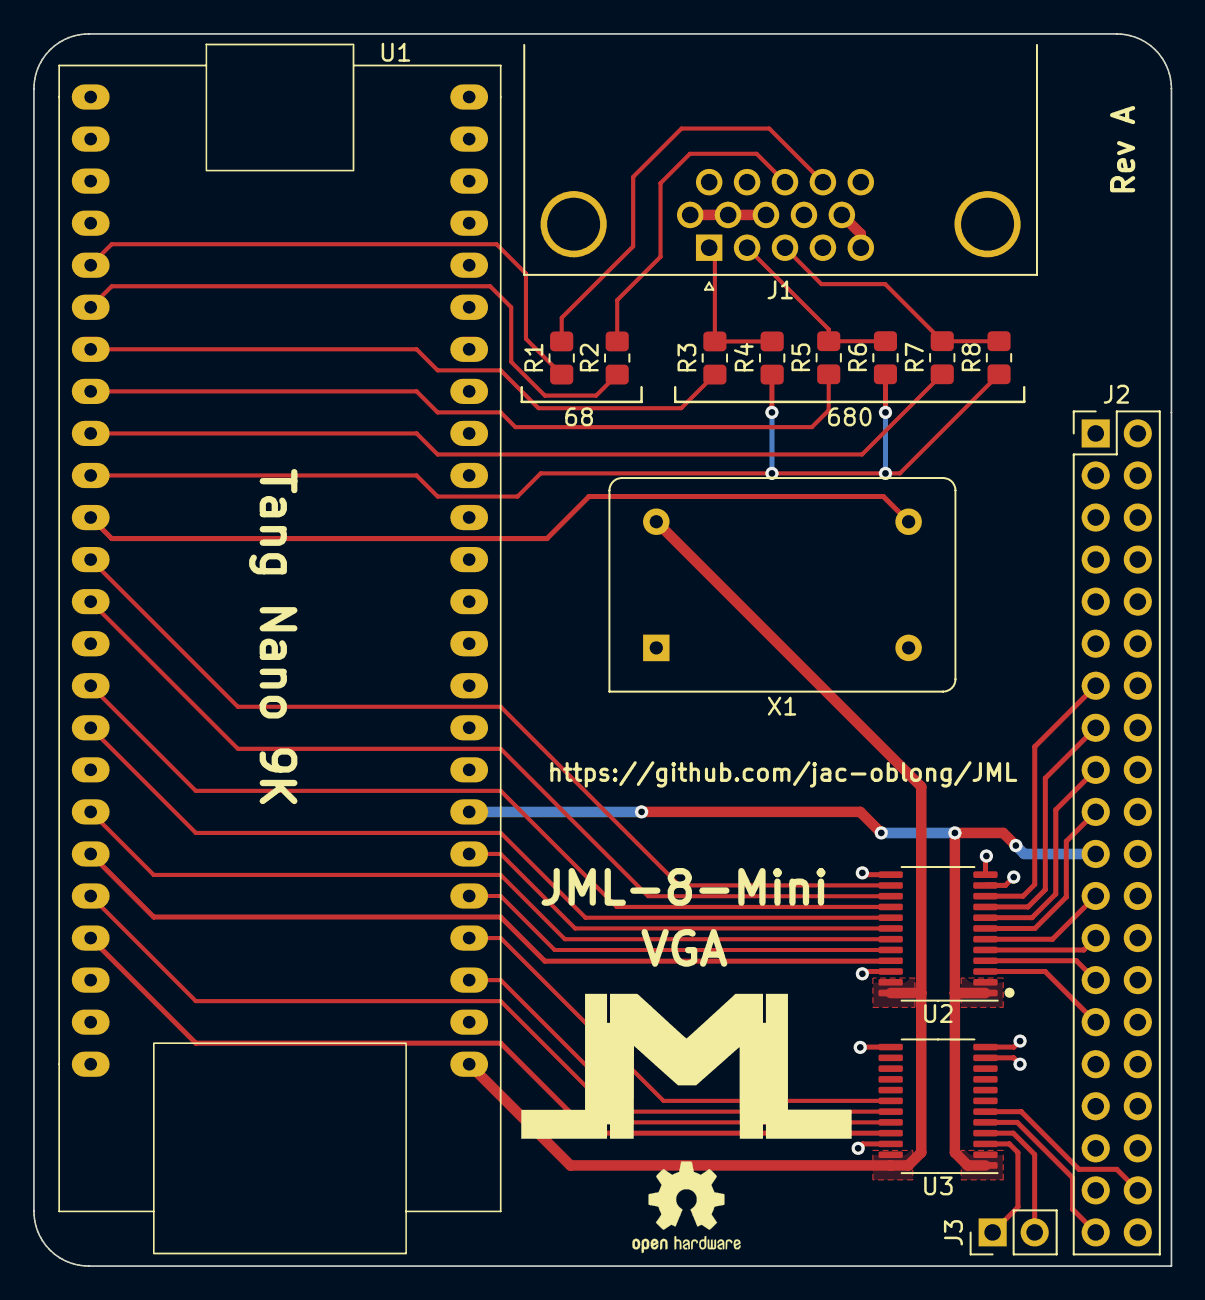
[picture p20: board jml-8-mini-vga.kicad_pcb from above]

Board: 2 copper layers, 68.7 x 74.4 mm, 15 parts (0 on the bottom side), 39 nets.

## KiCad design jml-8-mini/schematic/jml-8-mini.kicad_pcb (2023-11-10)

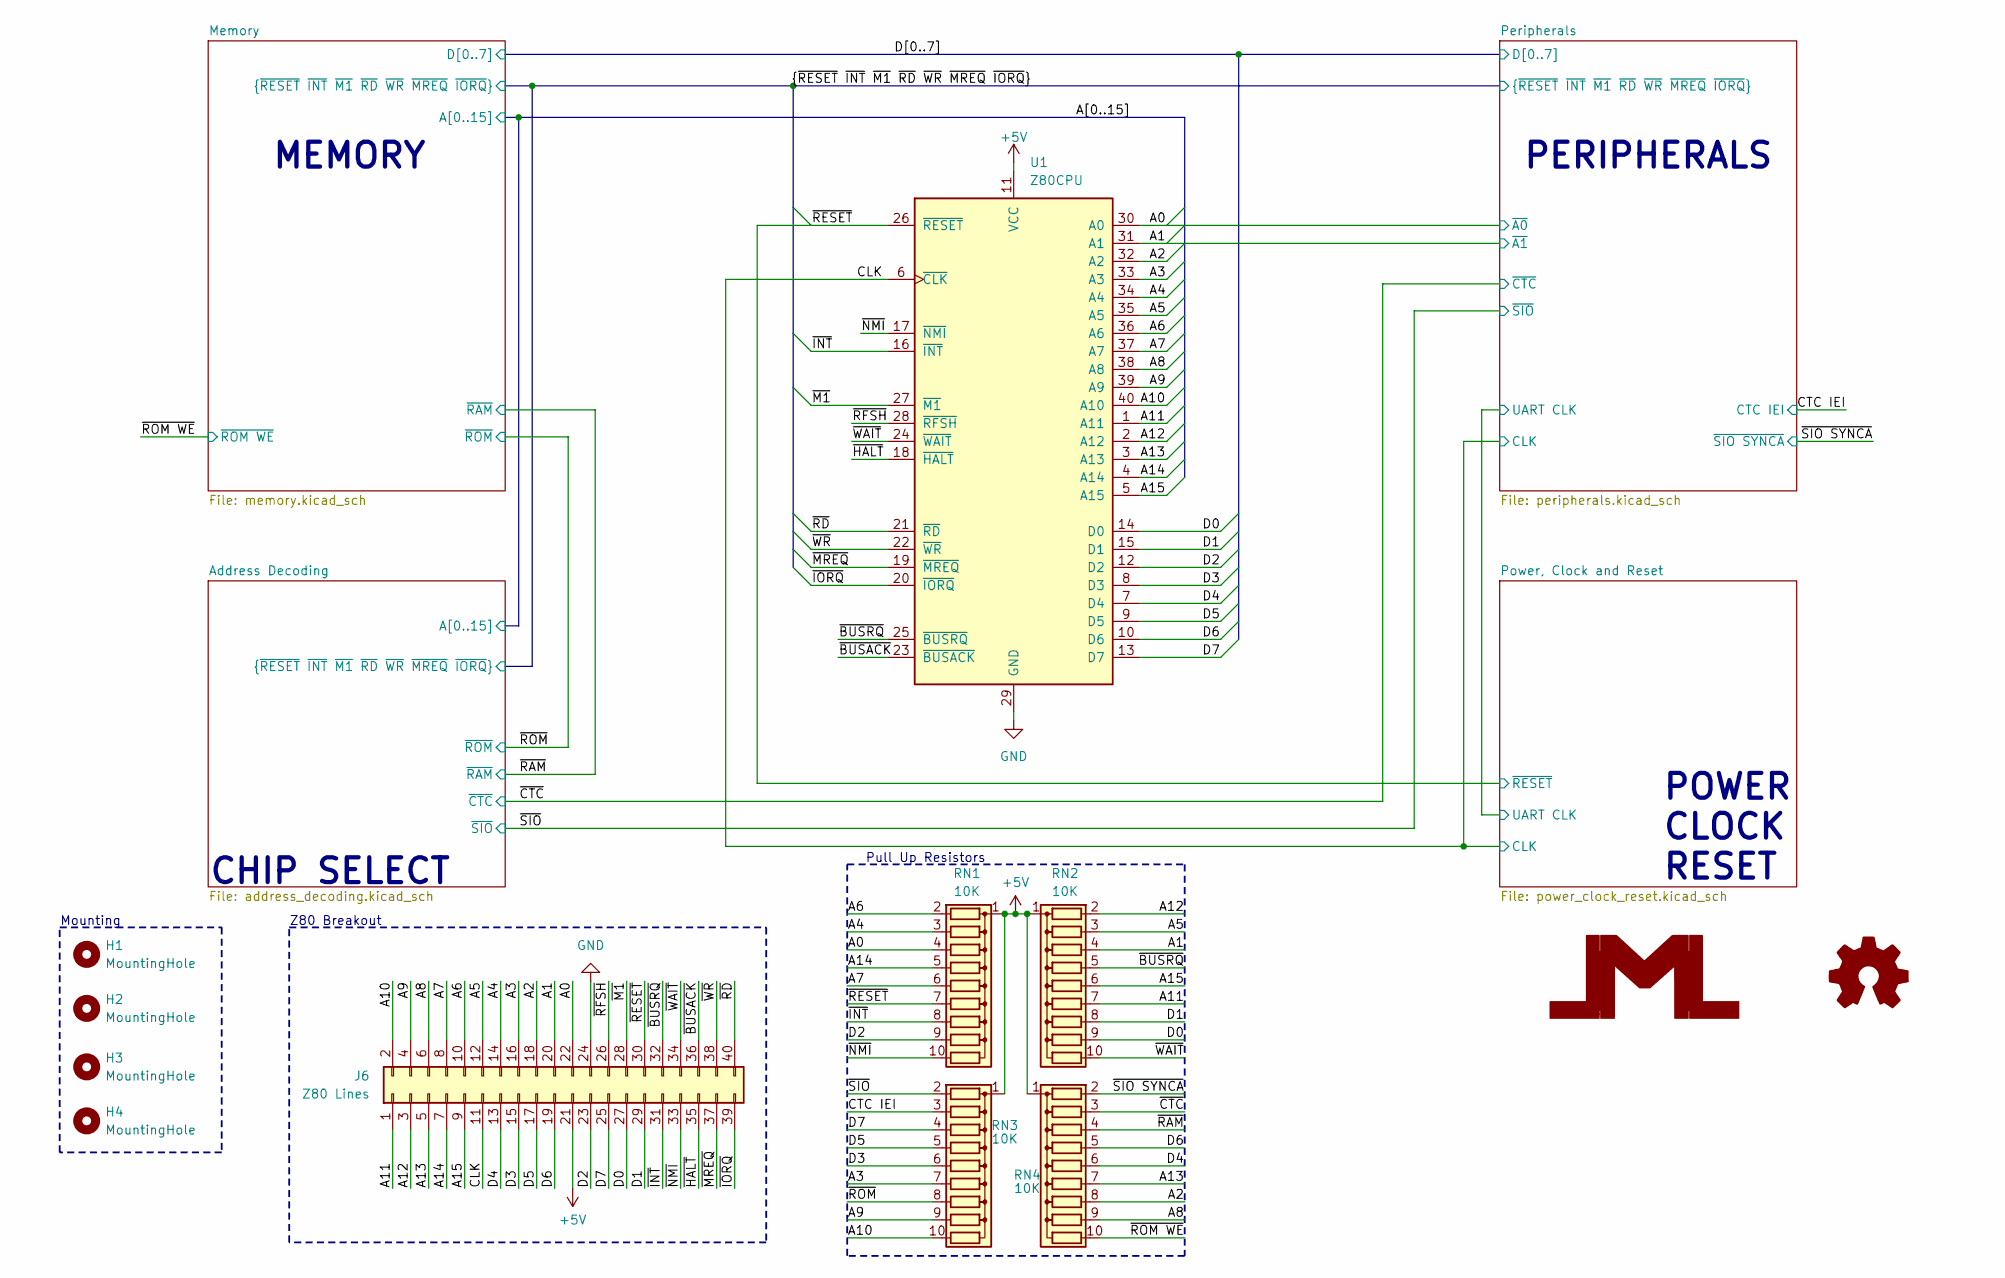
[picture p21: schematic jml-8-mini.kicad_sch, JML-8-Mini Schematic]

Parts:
H1, H2, H3, H4: MountingHole; MountingHole_2.7mm_M2.5
J6: Z80 Lines; PinHeader_2x20_P2.54mm_Vertical
RN1, RN2, RN3, RN4: 10K; R_Array_SIP10
U1: Z80CPU; DIP-40_W15.24mm_Socket_LongPads

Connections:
/A0: J6.22, RN1.4 (R3), U1.30 (A0); also elsewhere on the board
/A1: J6.20, RN2.4 (R3), U1.31 (A1); also elsewhere on the board
/A2: J6.18, RN4.8 (R7), U1.32 (A2); also elsewhere on the board
/A3: J6.16, RN3.7 (R6), U1.33 (A3); also elsewhere on the board
/A4: J6.14, RN1.3 (R2), U1.34 (A4); also elsewhere on the board
/A5: J6.12, RN2.3 (R2), U1.35 (A5); also elsewhere on the board
/A6: J6.10, RN1.2 (R1), U1.36 (A6); also elsewhere on the board
/A7: J6.8, RN1.6 (R5), U1.37 (A7); also elsewhere on the board
/A8: J6.6, RN4.9 (R8), U1.38 (A8); also elsewhere on the board
/A9: J6.4, RN3.9 (R8), U1.39 (A9); also elsewhere on the board
/A10: J6.2, RN3.10 (R9), U1.40 (A10); also elsewhere on the board
/A11: J6.1, RN2.7 (R6), U1.1 (A11); also elsewhere on the board
/A12: J6.3, RN2.2 (R1), U1.2 (A12); also elsewhere on the board
/A13: J6.5, RN4.7 (R6), U1.3 (A13); also elsewhere on the board
/A14: J6.7, RN1.5 (R4), U1.4 (A14); also elsewhere on the board
/CLK: J6.11, U1.6 (~CLK); also elsewhere on the board
/CTC IEI: RN3.3 (R2); also elsewhere on the board
/D0: J6.27, RN2.9 (R8), U1.14 (D0); also elsewhere on the board
/D1: J6.29, RN2.8 (R7), U1.15 (D1); also elsewhere on the board
/D2: J6.23, RN1.9 (R8), U1.12 (D2); also elsewhere on the board
/D3: J6.15, RN3.6 (R5), U1.8 (D3); also elsewhere on the board
/D4: J6.13, RN4.6 (R5), U1.7 (D4); also elsewhere on the board
/D5: J6.17, RN3.5 (R4), U1.9 (D5); also elsewhere on the board
/D6: J6.19, RN4.5 (R4), U1.10 (D6); also elsewhere on the board
/D7: J6.25, RN3.4 (R3), U1.13 (D7); also elsewhere on the board
/~BUSACK: J6.36, U1.23 (~BUSACK)
/~BUSRQ: J6.32, RN2.5 (R4), U1.25 (~BUSRQ)
/~CTC: RN4.3 (R2); also elsewhere on the board
/~HALT: J6.35, U1.18 (~HALT)
/~INT: J6.31, RN1.8 (R7), U1.16 (~INT); also elsewhere on the board
/~IORQ: J6.39, U1.20 (~IORQ); also elsewhere on the board
/~M1: J6.28, U1.27 (~M1); also elsewhere on the board
/~MREQ: J6.37, U1.19 (~MREQ); also elsewhere on the board
/~NMI: J6.33, RN1.10 (R9), U1.17 (~NMI)
/~RAM: RN4.4 (R3); also elsewhere on the board
/~RD: J6.40, U1.21 (~RD); also elsewhere on the board
/~RFSH: J6.26, U1.28 (~RFSH)
/~ROM WE: RN4.10 (R9); also elsewhere on the board
/~ROM: RN3.8 (R7); also elsewhere on the board
/~SIO SYNCA: RN4.2 (R1); also elsewhere on the board
/~SIO: RN3.2 (R1); also elsewhere on the board
/~WAIT: J6.34, RN2.10 (R9), U1.24 (~WAIT)
/~WR: J6.38, U1.22 (~WR); also elsewhere on the board

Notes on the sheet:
MEMORY
PERIPHERALS
CHIP SELECT
POWER CLOCK RESET
Z80 Breakout
Mounting
Pull Up Resistors

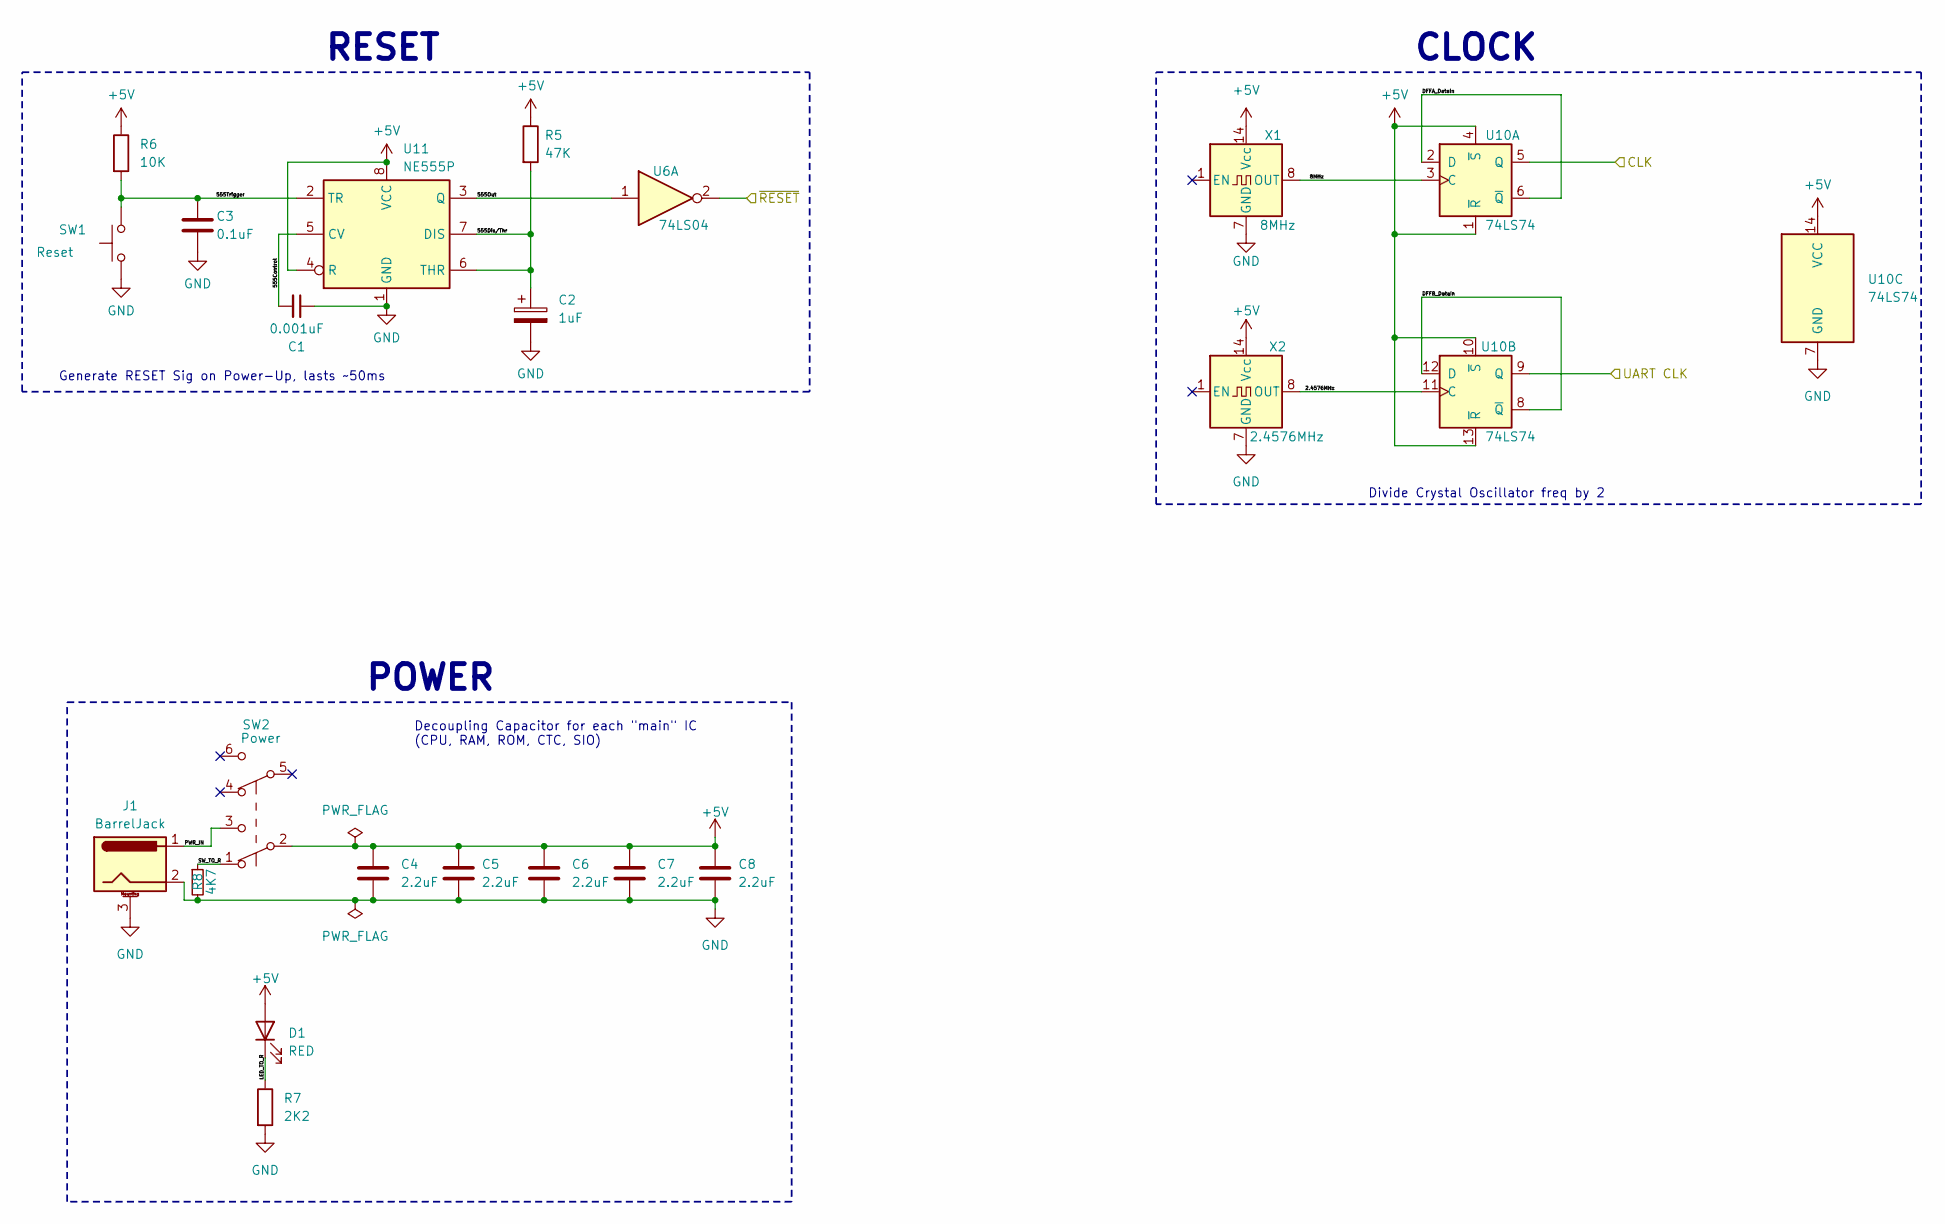
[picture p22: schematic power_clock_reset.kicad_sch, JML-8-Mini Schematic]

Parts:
C1: 0.001uF; C_Disc_D5.0mm_W2.5mm_P5.00mm
C2: 1uF; CP_Radial_D5.0mm_P2.50mm
C3: 0.1uF; C_Disc_D5.0mm_W2.5mm_P5.00mm
C4, C5, C6, C7, C8: 2.2uF; C_Disc_D5.0mm_W2.5mm_P5.00mm
D1: RED; LED_D5.0mm
J1: BarrelJack; BarrelJack_Horizontal
R5: 47K; R_Axial_DIN0207_L6.3mm_D2.5mm_P7.62mm_Horizontal
R6: 10K; R_Axial_DIN0207_L6.3mm_D2.5mm_P7.62mm_Horizontal
R7: 2K2; R_Axial_DIN0207_L6.3mm_D2.5mm_P7.62mm_Horizontal
R8: 4K7; R_Axial_DIN0207_L6.3mm_D2.5mm_P7.62mm_Horizontal
SW1: Reset; SW_Tactile_Straight_KSA0Axx1LFTR
SW2: Power; SW_Push_2P2T_Toggle_CK_PVA2xxH1xxxxxxV2
U6: 74LS04; DIP-14_W7.62mm_Socket_LongPads
U10: 74LS74; DIP-14_W7.62mm_Socket_LongPads
U11: NE555P; DIP-8_W7.62mm_Socket_LongPads
X1: 8MHz; Oscillator_DIP-14
X2: 2.4576MHz; Oscillator_DIP-14

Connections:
/CLK: U10.5 (Q); also elsewhere on the board
/Peripherals/UART CLK: U10.9 (Q); also elsewhere on the board
/Power, Clock and Reset/2.4576MHz: U10.11 (C), X2.8 (OUT)
/Power, Clock and Reset/8MHz: U10.3 (C), X1.8 (OUT)
/Power, Clock and Reset/555Control: C1.2, U11.5 (CV)
/Power, Clock and Reset/555Dis/Thr: C2.1, R5.2, U11.6 (THR), U11.7 (DIS)
/Power, Clock and Reset/555Trigger: C3.1, R6.2, SW1.2, U11.2 (TR)
/Power, Clock and Reset/DFFA_DataIn: U10.2 (D), U10.6 (~Q)
/Power, Clock and Reset/DFFB_DataIn: U10.8 (~Q), U10.12 (D)
/Power, Clock and Reset/LED_TO_R: D1.1 (K), R7.1
/Power, Clock and Reset/PWR_IN: J1.1, SW2.3 (C)
/Power, Clock and Reset/SW_TO_R: R8.1, SW2.1 (A)

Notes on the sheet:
Generate RESET Sig on Power-Up, lasts ~50ms
RESET
CLOCK
POWER
Divide Crystal Oscillator freq by 2
Decoupling Capacitor for each "main" IC (CPU, RAM, ROM, CTC, SIO)

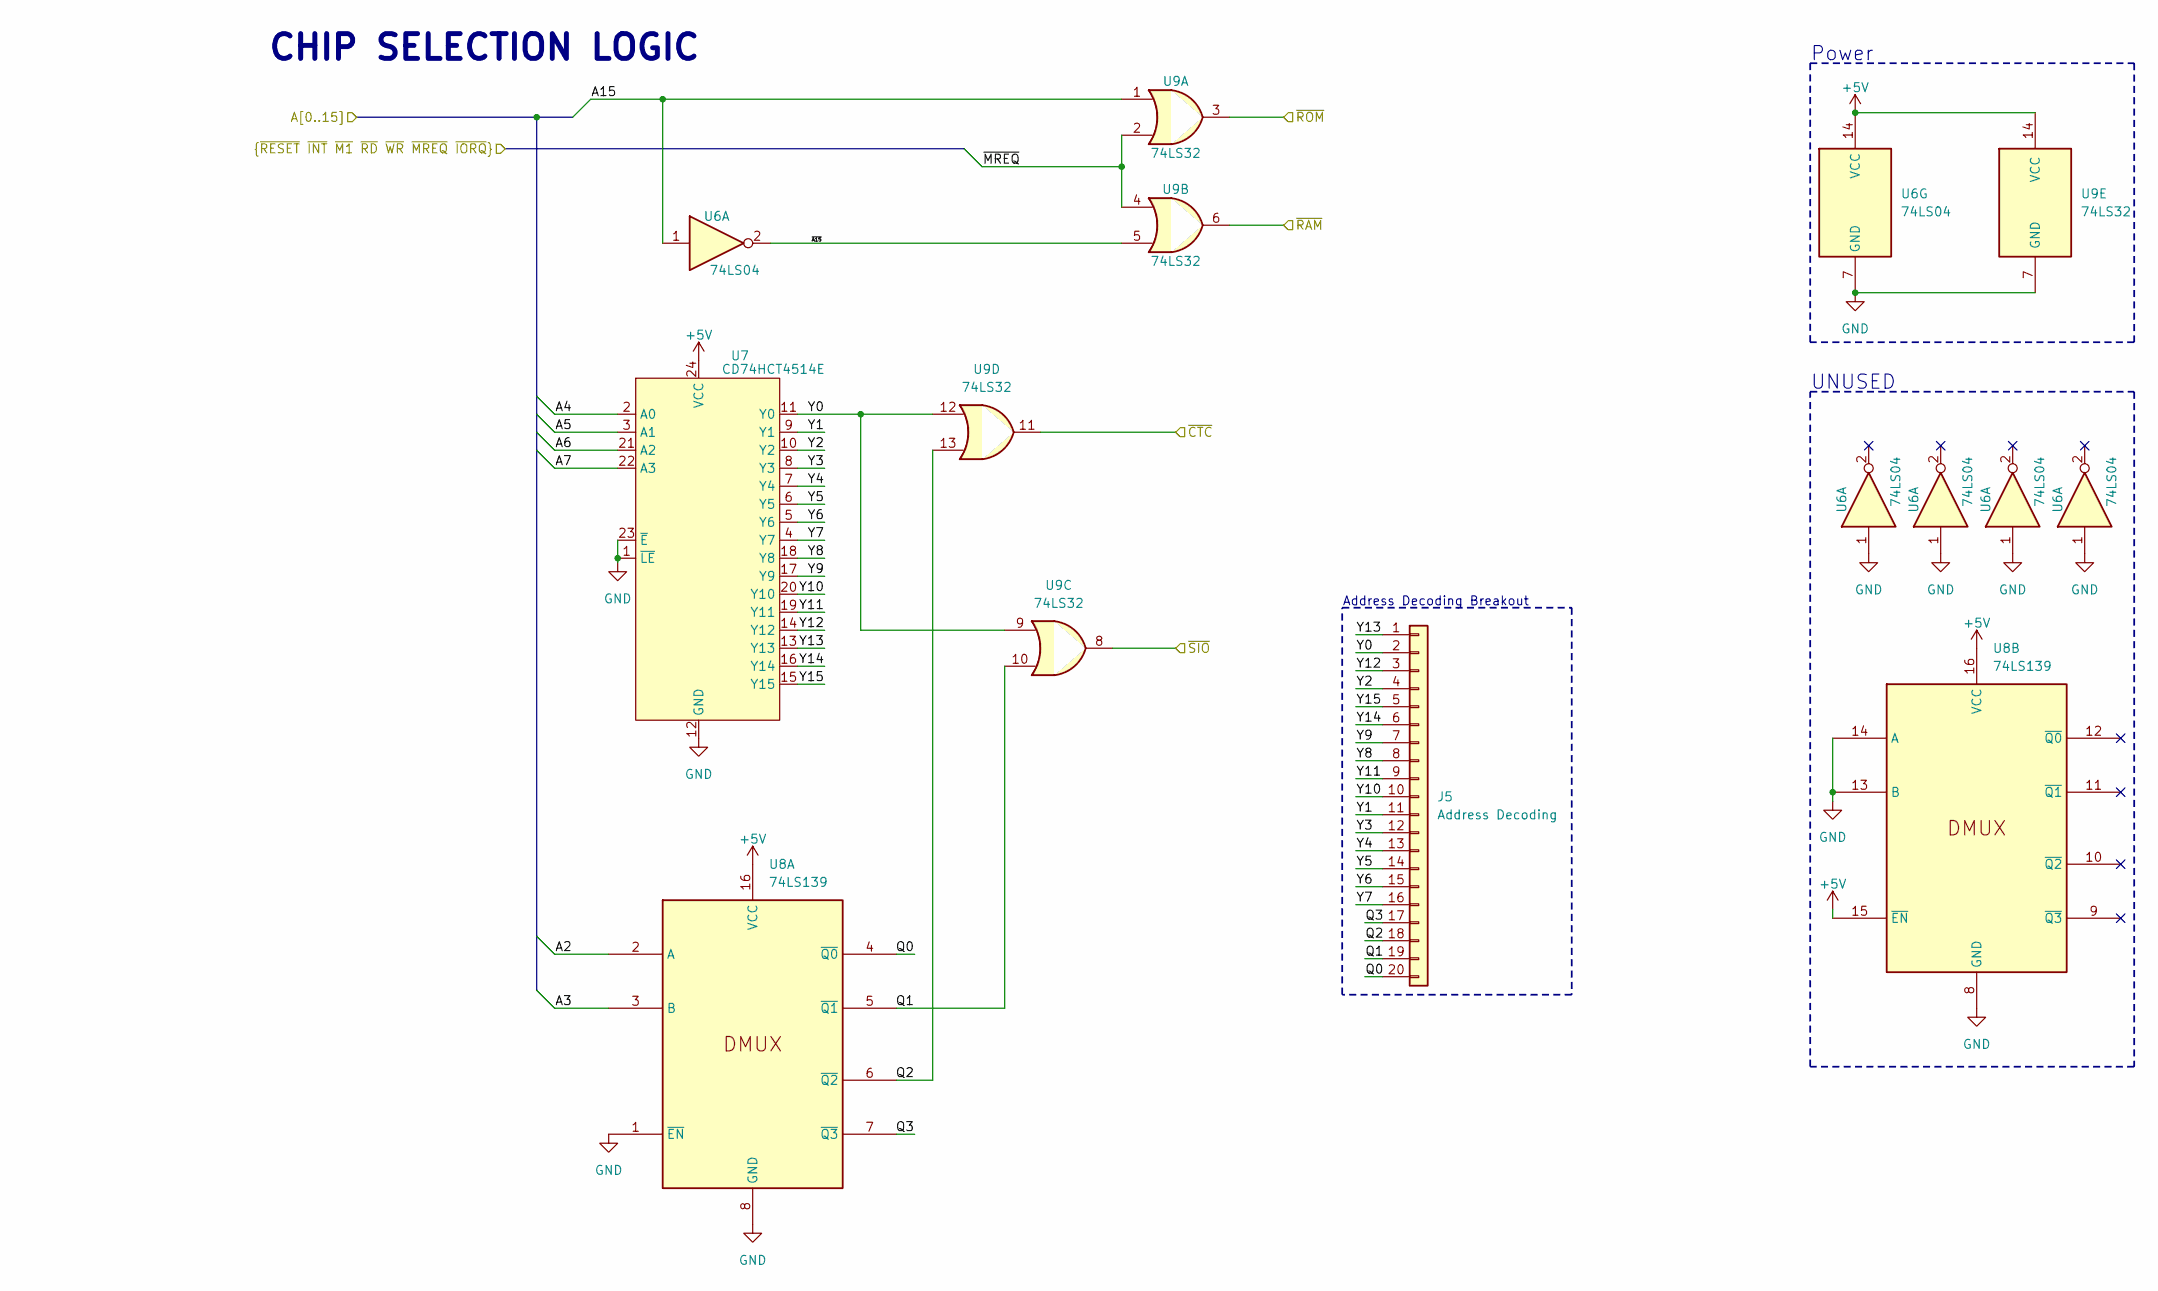
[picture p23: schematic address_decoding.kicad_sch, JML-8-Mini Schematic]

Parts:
J5: Address Decoding; PinHeader_1x20_P2.54mm_Vertical
U6: 74LS04; DIP-14_W7.62mm_Socket_LongPads
U7: CD74HCT4514E; DIP-24_W15.24mm_Socket_LongPads
U8: 74LS139; DIP-16_W7.62mm_Socket_LongPads
U9: 74LS32; DIP-14_W7.62mm_Socket_LongPads

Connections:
/A2: U8.2 (A); also elsewhere on the board
/A3: U8.3 (B); also elsewhere on the board
/A4: U7.2 (A0); also elsewhere on the board
/A5: U7.3 (A1); also elsewhere on the board
/A6: U7.21 (A2); also elsewhere on the board
/A7: U7.22 (A3); also elsewhere on the board
/Address Decoding/Q0: J5.20, U8.4 (~Q0)
/Address Decoding/Q1: J5.19, U8.5 (~Q1), U9.10
/Address Decoding/Q2: J5.18, U8.6 (~Q2), U9.13
/Address Decoding/Q3: J5.17, U8.7 (~Q3)
/Address Decoding/Y0: J5.2, U7.11 (Y0), U9.9, U9.12
/Address Decoding/Y1: J5.11, U7.9 (Y1)
/Address Decoding/Y2: J5.4, U7.10 (Y2)
/Address Decoding/Y3: J5.12, U7.8 (Y3)
/Address Decoding/Y4: J5.13, U7.7 (Y4)
/Address Decoding/Y5: J5.14, U7.6 (Y5)
/Address Decoding/Y6: J5.15, U7.5 (Y6)
/Address Decoding/Y7: J5.16, U7.4 (Y7)
/Address Decoding/Y8: J5.8, U7.18 (Y8)
/Address Decoding/Y9: J5.7, U7.17 (Y9)
/Address Decoding/Y10: J5.10, U7.20 (Y10)
/Address Decoding/Y11: J5.9, U7.19 (Y11)
/Address Decoding/Y12: J5.3, U7.14 (Y12)
/Address Decoding/Y13: J5.1, U7.13 (Y13)
/Address Decoding/Y14: J5.6, U7.16 (Y14)
/Address Decoding/Y15: J5.5, U7.15 (Y15)
/~CTC: U9.11; also elsewhere on the board
/~MREQ: U9.2, U9.4; also elsewhere on the board
/~RAM: U9.6; also elsewhere on the board
/~ROM: U9.3; also elsewhere on the board
/~SIO: U9.8; also elsewhere on the board

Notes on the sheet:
Address Decoding Breakout
UNUSED
Power
CHIP SELECTION LOGIC

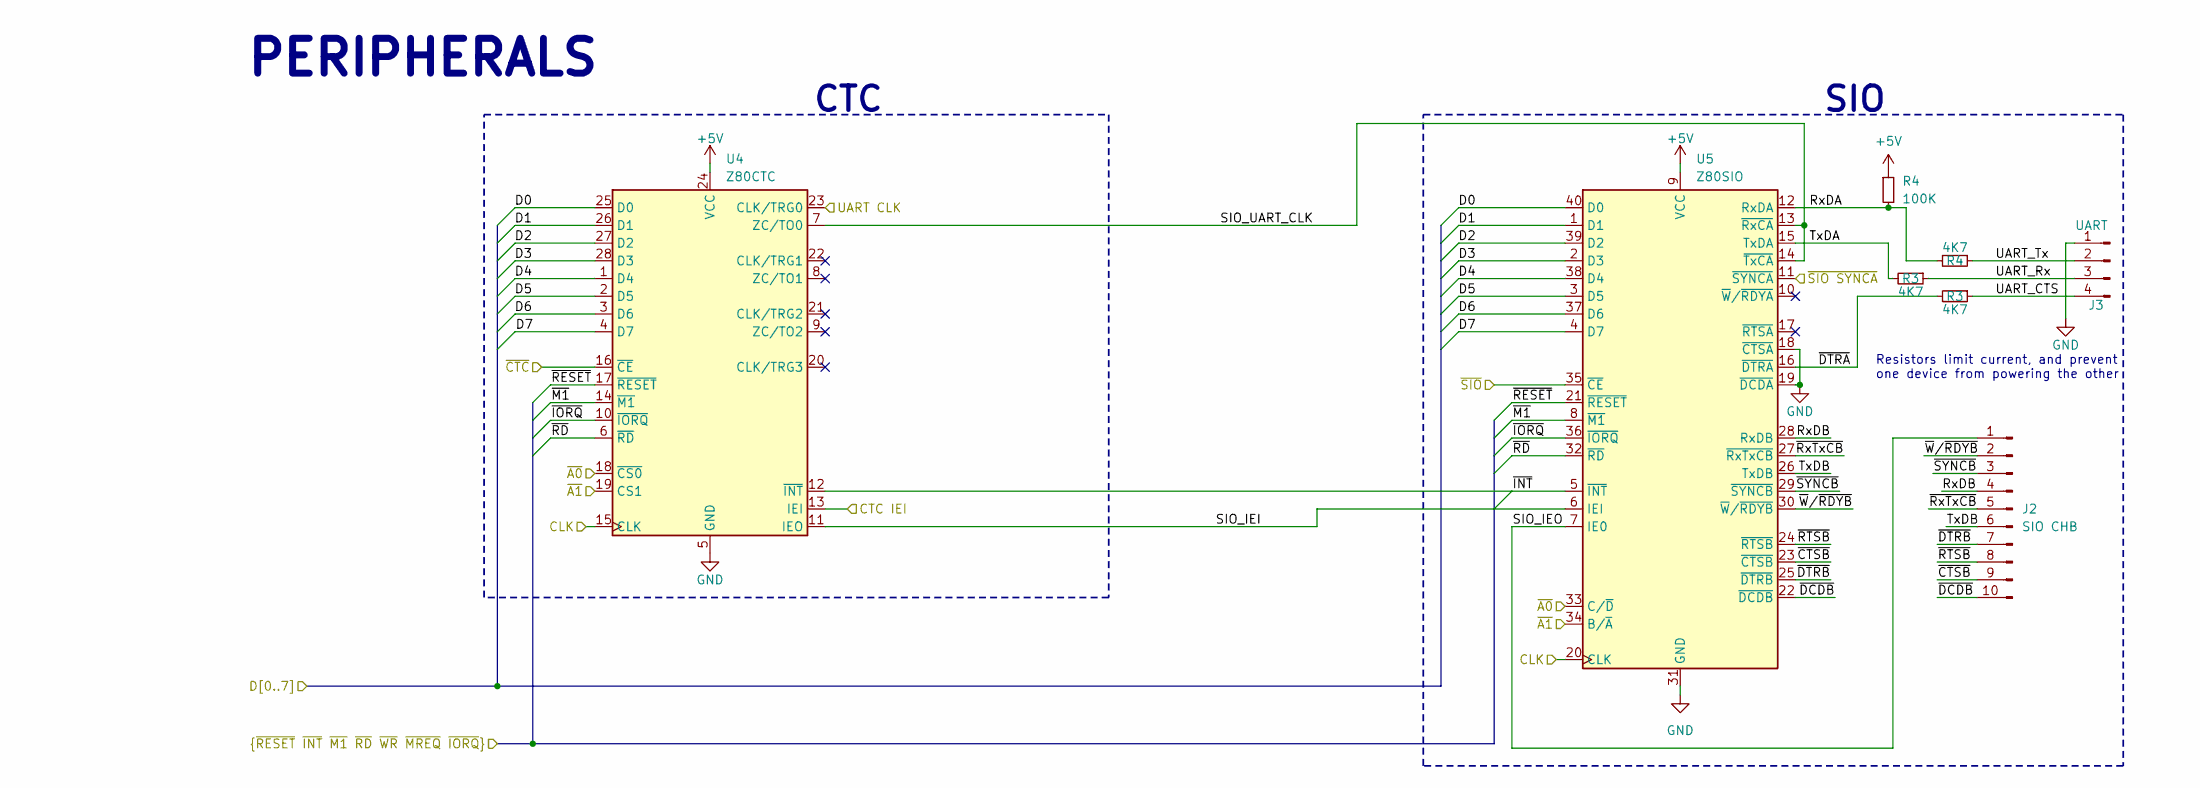
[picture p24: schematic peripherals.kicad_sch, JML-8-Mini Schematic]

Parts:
J2: SIO CHB; PinHeader_1x10_P2.54mm_Vertical
J3: UART; PinHeader_1x04_P2.54mm_Horizontal
R3, R4: 4K7; R_Axial_DIN0207_L6.3mm_D2.5mm_P7.62mm_Horizontal
U4: Z80CTC; DIP-28_W15.24mm_Socket_LongPads
U5: Z80SIO; DIP-40_W15.24mm_Socket_LongPads

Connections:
/A0: U4.18 (~CS0), U5.33 (C/~D); also elsewhere on the board
/A1: U4.19 (CS1), U5.34 (B/~A); also elsewhere on the board
/CLK: U4.15 (CLK), U5.20 (CLK); also elsewhere on the board
/CTC IEI: U4.13 (IEI); also elsewhere on the board
/D0: U4.25 (D0), U5.40 (D0); also elsewhere on the board
/D1: U4.26 (D1), U5.1 (D1); also elsewhere on the board
/D2: U4.27 (D2), U5.39 (D2); also elsewhere on the board
/D3: U4.28 (D3), U5.2 (D3); also elsewhere on the board
/D4: U4.1 (D4), U5.38 (D4); also elsewhere on the board
/D5: U4.2 (D5), U5.3 (D5); also elsewhere on the board
/D6: U4.3 (D6), U5.37 (D6); also elsewhere on the board
/D7: U4.4 (D7), U5.4 (D7); also elsewhere on the board
/Peripherals/RxDA: R4.2, U5.12 (RxDA); also elsewhere on the board
/Peripherals/RxDB: J2.4, U5.28 (RxDB)
/Peripherals/SIO_IEI: U4.11 (IEO), U5.6 (IEI)
/Peripherals/SIO_IEO: J2.1, U5.7 (IE0)
/Peripherals/SIO_UART_CLK: U4.7 (ZC/TO0), U5.13 (~RxCA), U5.14 (~TxCA)
/Peripherals/TxDB: J2.6, U5.26 (TxDB)
/Peripherals/UART CLK: U4.23 (CLK/TRG0); also elsewhere on the board
/Peripherals/~CTSB: J2.9, U5.23 (~CTSB)
/Peripherals/~DCDB: J2.10, U5.22 (~DCDB)
/Peripherals/~DTRB: J2.7, U5.25 (~DTRB)
/Peripherals/~RTSB: J2.8, U5.24 (~RTSB)
/Peripherals/~RxTxCB: J2.5, U5.27 (~RxTxCB)
/Peripherals/~SYNCB: J2.3, U5.29 (~SYNCB)
/Peripherals/~W/~RDYB: J2.2, U5.30 (~W/~RDYB)
/~CTC: U4.16 (~CE); also elsewhere on the board
/~INT: U4.12 (~INT), U5.5 (~INT); also elsewhere on the board
/~IORQ: U4.10 (~IORQ), U5.36 (~IORQ); also elsewhere on the board
/~M1: U4.14 (~M1), U5.8 (~M1); also elsewhere on the board
/~RD: U4.6 (~RD), U5.32 (~RD); also elsewhere on the board
/~SIO SYNCA: U5.11 (~SYNCA); also elsewhere on the board
/~SIO: U5.35 (~CE); also elsewhere on the board

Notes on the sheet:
Resistors limit current, and prevent one device from powering the other
CTC
SIO
PERIPHERALS

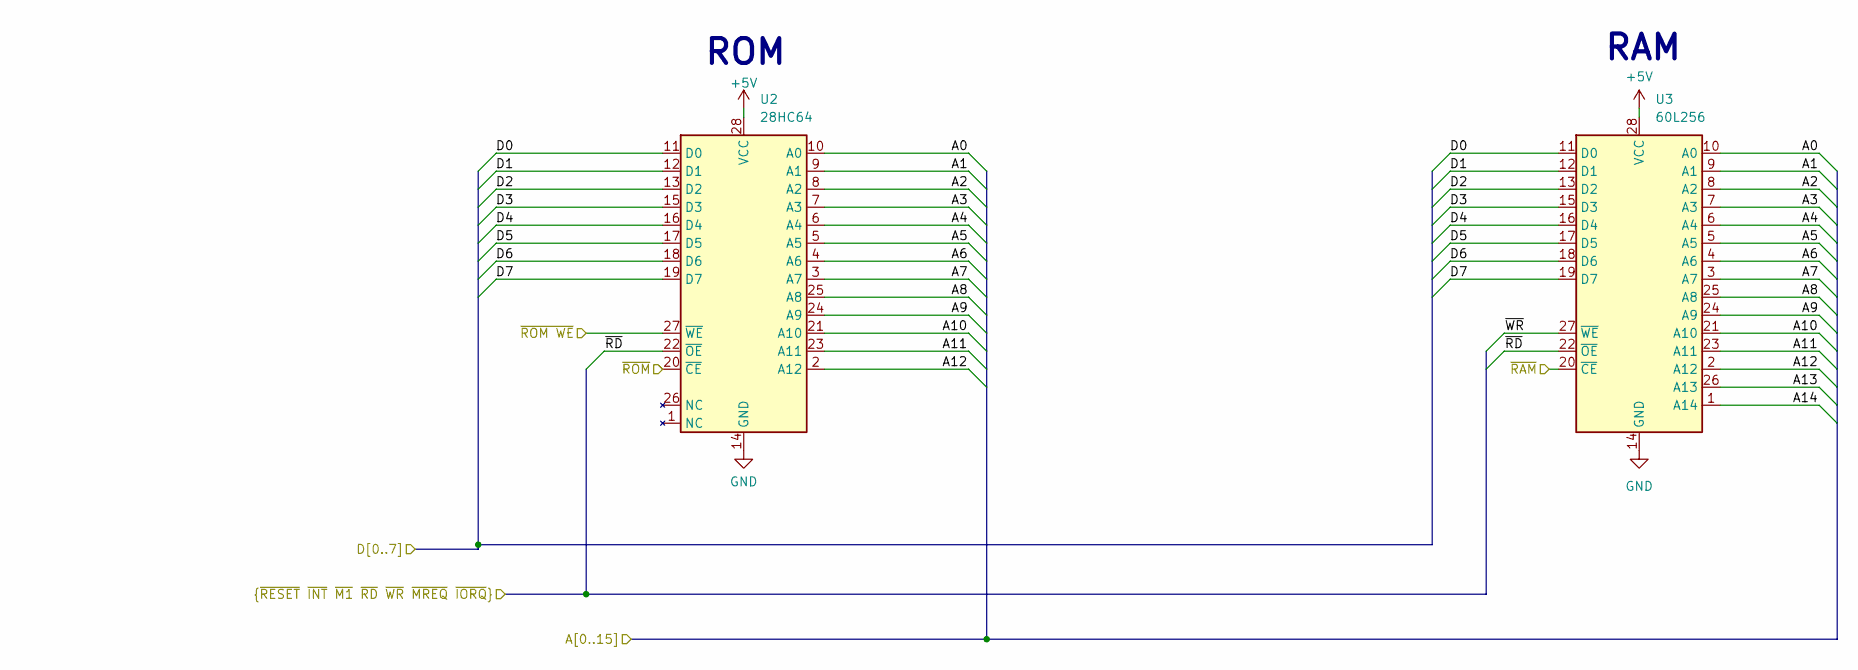
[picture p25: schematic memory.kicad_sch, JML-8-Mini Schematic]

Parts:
U2: 28HC64; DIP-28_W15.24mm_Socket_LongPads
U3: 60L256; DIP-28_W15.24mm_Socket_LongPads

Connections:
/A0: U2.10 (A0), U3.10 (A0); also elsewhere on the board
/A1: U2.9 (A1), U3.9 (A1); also elsewhere on the board
/A2: U2.8 (A2), U3.8 (A2); also elsewhere on the board
/A3: U2.7 (A3), U3.7 (A3); also elsewhere on the board
/A4: U2.6 (A4), U3.6 (A4); also elsewhere on the board
/A5: U2.5 (A5), U3.5 (A5); also elsewhere on the board
/A6: U2.4 (A6), U3.4 (A6); also elsewhere on the board
/A7: U2.3 (A7), U3.3 (A7); also elsewhere on the board
/A8: U2.25 (A8), U3.25 (A8); also elsewhere on the board
/A9: U2.24 (A9), U3.24 (A9); also elsewhere on the board
/A10: U2.21 (A10), U3.21 (A10); also elsewhere on the board
/A11: U2.23 (A11), U3.23 (A11); also elsewhere on the board
/A12: U2.2 (A12), U3.2 (A12); also elsewhere on the board
/A13: U3.26 (A13); also elsewhere on the board
/A14: U3.1 (A14); also elsewhere on the board
/D0: U2.11 (D0), U3.11 (D0); also elsewhere on the board
/D1: U2.12 (D1), U3.12 (D1); also elsewhere on the board
/D2: U2.13 (D2), U3.13 (D2); also elsewhere on the board
/D3: U2.15 (D3), U3.15 (D3); also elsewhere on the board
/D4: U2.16 (D4), U3.16 (D4); also elsewhere on the board
/D5: U2.17 (D5), U3.17 (D5); also elsewhere on the board
/D6: U2.18 (D6), U3.18 (D6); also elsewhere on the board
/D7: U2.19 (D7), U3.19 (D7); also elsewhere on the board
/~RAM: U3.20 (~CE); also elsewhere on the board
/~RD: U2.22 (~OE), U3.22 (~OE); also elsewhere on the board
/~ROM WE: U2.27 (~WE); also elsewhere on the board
/~ROM: U2.20 (~CE); also elsewhere on the board
/~WR: U3.27 (~WE); also elsewhere on the board

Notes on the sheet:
RAM
ROM

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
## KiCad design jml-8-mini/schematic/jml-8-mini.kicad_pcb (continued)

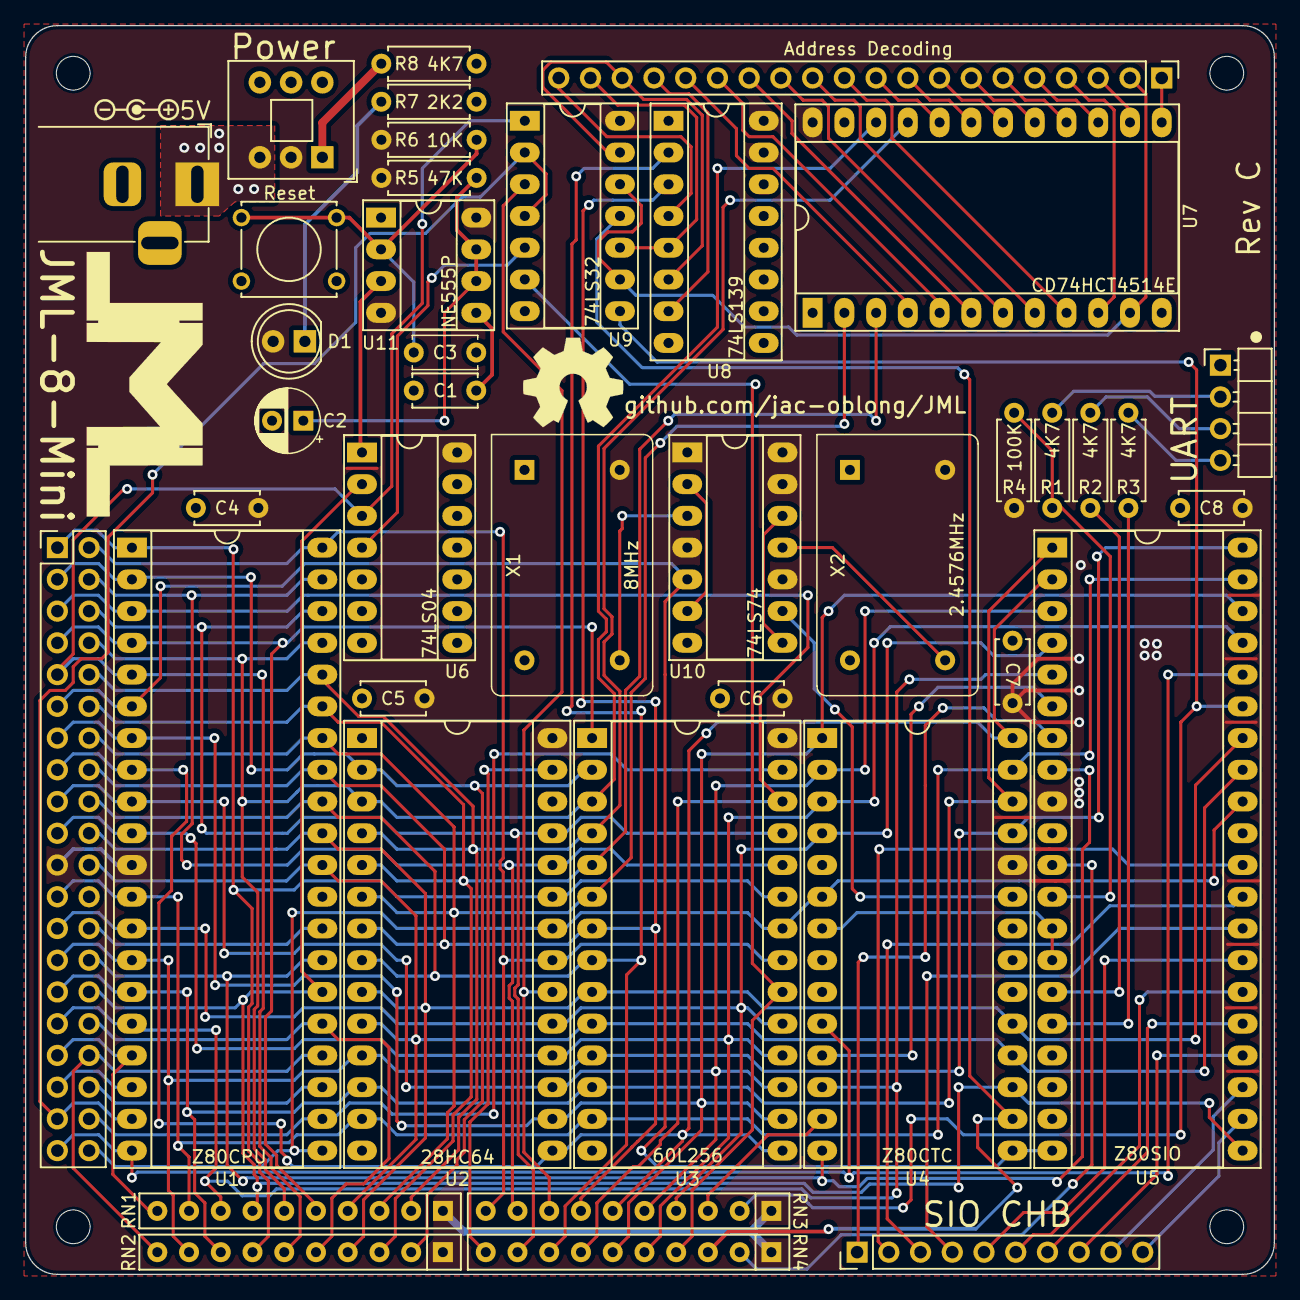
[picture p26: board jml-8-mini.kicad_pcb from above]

Board: 4 copper layers, 99.9 x 99.9 mm, 45 parts (0 on the bottom side), 98 nets.

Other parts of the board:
R1, R2: 4K7; R_Axial_DIN0207_L6.3mm_D2.5mm_P7.62mm_Horizontal

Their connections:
/Peripherals/RxDA: R1.2; also elsewhere on the board

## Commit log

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2023-06-21 rework assembler to be easier to understand
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2023-08-30 start creating schematic for rom-utilities
    [rom-utilities.kicad_pcb, rom-utilities.kicad_sch]
2023-08-30 update to schematic
    [rom-utilities.kicad_sch]
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2023-09-04 remove unnecessary project
    [rom-utilities.kicad_pcb, rom-utilities.kicad_sch]
2023-09-07 begin working on schematic for jml-8 mini
    [jml-8-mini.kicad_pcb, jml-8-mini.kicad_sch]
2023-09-09 updates to jml-8 mini schematic
    [address_decoding.kicad_sch, clock.kicad_sch, jml-8-mini.kicad_sch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]
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2023-09-12 update schematic, new program to test RAM
    [address_decoding.kicad_sch, jml-8-mini.kicad_sch]
2023-09-22 updates to schematics
    [address_decoding.kicad_sch, jml-8-mini.kicad_sch]
2023-09-23 many changes to schematic to make more organized
    [address_decoding.kicad_sch, clock_reset.kicad_sch, jml-8-mini.kicad_sch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]
2023-09-24 lots of changes to schematic, redone to make easier to read and add to
    [address_decoding.kicad_sch, jml-8-mini.kicad_sch, memory.kicad_sch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]
2023-09-25 updates to schematic, generally making formatting better
    [memory.kicad_sch, peripherals.kicad_sch]
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2023-10-01 minor updates to schematic
    [jml-8-mini.kicad_sch, memory.kicad_sch, peripherals.kicad_sch]
2023-10-01 fix bug in makefile, clean before assembling
2023-10-03 complete schematic
    [address_decoding.kicad_sch, jml-8-mini.kicad_sch, memory.kicad_sch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]
2023-10-03 add to info section of schematic
    [address_decoding.kicad_sch, jml-8-mini.kicad_sch, memory.kicad_sch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]
2023-10-05 update SIO and CTC library symbols to better match datasheet
    [peripherals.kicad_sch]
2023-10-05 update info section of schematic
    [address_decoding.kicad_sch, jml-8-mini.kicad_sch, memory.kicad_sch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]
2023-10-05 add mounting holes for PCB
    [jml-8-mini.kicad_sch]
2023-10-05 general "neatening" of schematics
    [memory.kicad_sch, peripherals.kicad_sch, power_clock_reset.kicad_sch]
2023-10-06 change some footprints
    [address_decoding.kicad_sch, memory.kicad_sch, peripherals.kicad_sch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]
2023-10-06 change more footprints
    [jml-8-mini.kicad_sch]
2023-10-06 add resistor so caps discharge slower when power cuts off
    [power_clock_reset.kicad_sch]
2023-10-06 swap pins on resistor network for easier pcb connection
    [jml-8-mini.kicad_sch]
2023-10-06 idk what this is, it just keeps happening?
    [memory.kicad_sch]
2023-10-09 lots of updates to schematic to make pcb routing easier, start on pcb design
    [address_decoding.kicad_sch, jml-8-mini.kicad_pcb, jml-8-mini.kicad_sch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]
2023-10-10 making pcb 4 layers instead of 2, restarting routing, more exact outline dimensions
    [jml-8-mini.kicad_pcb]
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2023-10-12 fix wrong label, add labels and figures to pcb
    [jml-8-mini.kicad_pcb, jml-8-mini.kicad_sch, memory.kicad_sch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]
2023-10-13 add JML logo to pcb
    [jml-8-mini.kicad_pcb]
2023-10-14 new symbol & footprint for logo, add to schematic and pcb
    [jml-8-mini.kicad_pcb, jml-8-mini.kicad_sch]
2023-10-16 create gerbers for pcb
    [jml-8-mini-B_Cu.gbr, jml-8-mini-B_Mask.gbr, jml-8-mini-B_Paste.gbr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]
2023-10-16 updates to gerber files
    [jml-8-mini-B_Cu.gbr, jml-8-mini-B_Mask.gbr, jml-8-mini-B_Paste.gbr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]
2023-10-16 fix some errors in schematic/pcb
    [address_decoding.kicad_sch, jml-8-mini.kicad_pcb, memory.kicad_sch]
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2023-10-16 updates to silkscreen, regenerate gerbers
    [jml-8-mini-B_Cu.gbr, jml-8-mini-B_Mask.gbr, jml-8-mini-B_Paste.gbr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]
2023-10-16 minor changes to silkscreen, update gerbers
    [jml-8-mini-B_Cu.gbr, jml-8-mini-B_Mask.gbr, jml-8-mini-B_Paste.gbr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]
2023-10-17 add ground plane to top and bottom, fix silkscreen, regenerate gerbers
    [jml-8-mini-B_Cu.gbr, jml-8-mini-B_Mask.gbr, jml-8-mini-B_Paste.gbr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]
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2023-10-18 change "JML-8 Mini" to "JML-8-Mini" in schematic description
    [address_decoding.kicad_sch, jml-8-mini.kicad_sch, memory.kicad_sch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]
2023-10-18 minor changes to ground plane on front and back layer, regenerate gerbers
    [jml-8-mini-B_Cu.gbr, jml-8-mini-B_Mask.gbr, jml-8-mini-B_Paste.gbr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]
2023-10-21 remove CTC header pins, start Rev B
    [address_decoding.kicad_sch, memory.kicad_sch, peripherals.kicad_sch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]
2023-10-21 Rev B, change dimensions of PCB for reduced cost
    [jml-8-mini.kicad_pcb, jml-8-mini.kicad_sch]
2023-10-22 more updates for new PCB design
    [jml-8-mini.kicad_pcb]
2023-10-23 finish rerouting PCB for Rev B
    [jml-8-mini.kicad_pcb, jml-8-mini.kicad_sch]
2023-10-23 regenerate gerbers for Rev B PCB
    [jml-8-mini-B_Cu.gbr, jml-8-mini-B_Mask.gbr, jml-8-mini-B_Paste.gbr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]
2023-10-23 change layers 2 & 3 to GND and put PWR on top and bottom, regenerate gerbers
    [jml-8-mini-B_Cu.gbr, jml-8-mini-B_Mask.gbr, jml-8-mini-B_Paste.gbr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]
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2023-11-06 fix two capacitor footprints being swapped
    [jml-8-mini.kicad_pcb, power_clock_reset.kicad_sch]
2023-11-06 fix incorrect value for resistor
    [jml-8-mini.kicad_pcb, peripherals.kicad_sch]
2023-11-06 create REV C with new changes, update gerbers
    [address_decoding.kicad_sch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]
2023-11-08 PCB image and schematic pdf
    [jml-8-mini.csv]
2023-11-09 start working on case for jml-8-mini
    [jml-8-mini-case.FCStd]
2023-11-10 add origin to pcb file
    [jml-8-mini.kicad_pcb]
2023-11-10 get better 3d model of switch
    [jml-8-mini.kicad_pcb]
2023-11-10 import pcb step file into case design
    [jml-8-mini-case.FCStd]
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2023-12-15 begin working on JML-6502-Mini schematic
    [jml-6502-mini.kicad_pcb, jml-6502-mini.kicad_sch]
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2024-01-21 create schematic and pcb for jml-8-mini VGA daughterboard
    [jml-8-mini-vga-B_Cu.gbr, jml-8-mini-vga-B_Mask.gbr, jml-8-mini-vga-B_Paste.gbr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]
2024-01-23 add address decoding circuitry, regenerate gerbers
    [jml-8-mini-vga-B_Cu.gbr, jml-8-mini-vga-B_Mask.gbr, jml-8-mini-vga-B_Paste.gbr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]
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

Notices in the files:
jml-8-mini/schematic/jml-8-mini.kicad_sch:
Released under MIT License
